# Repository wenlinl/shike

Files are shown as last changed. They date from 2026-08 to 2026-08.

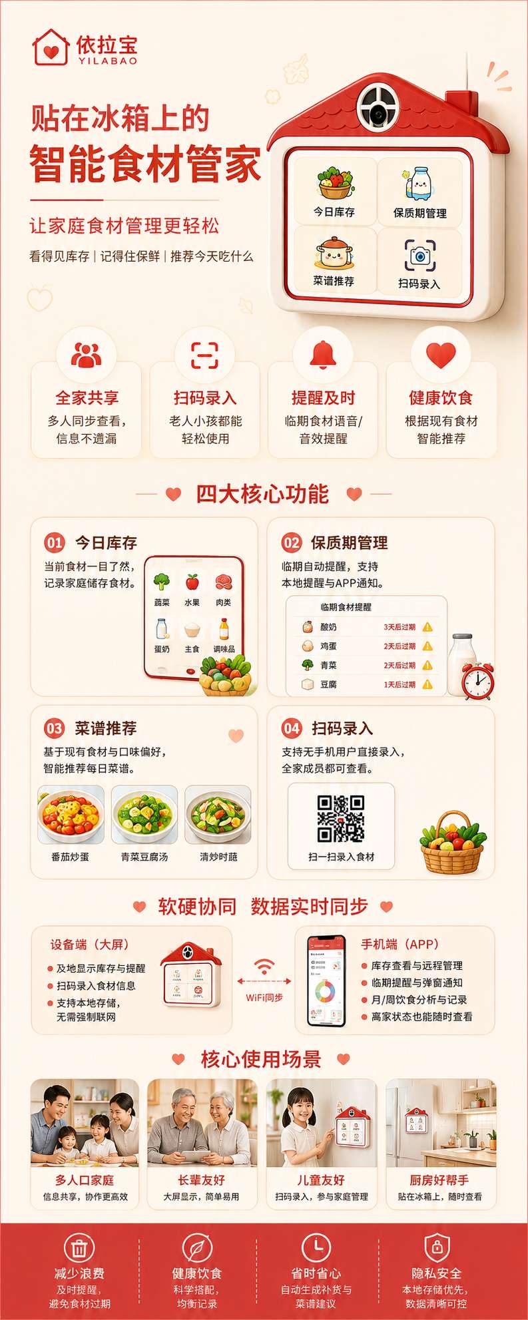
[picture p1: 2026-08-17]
media/产品宣传图/03-宣传海报-B.jpg

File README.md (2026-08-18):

# 食刻 ShiKe · 冰箱食品保质期智能管理

> Slogan：**食刻在场，不浪费每一份食材**

食刻是一台贴在冰箱上的 AI 食品扫描台：把食品拿到镜头前扫一下，云端 AI 认出它是什么、能放多久，库存自动记账；屏幕、手机端和大屏随时告诉你谁快过期、能做什么菜。

核心链路：**扫（拍照）→ 认（云端视觉 AI）→ 记（库存 ±1）→ 显（屏幕 + H5 + 大屏）**，已作为端到端可演示产品跑通——已有可演示原型机、硬件已烧录、后端已上线、H5/大屏可用、3D 打印外壳完成。

---

## 在线演示

| 入口 | 链接 | 说明 |
|---|---|---|
| H5 手机端 | https://tuvmkt.com/shike-h5.html | 首页 / 扫描 / 库存 / 菜谱 / 我的（iPhone 适配） |
| 大屏版 | https://tuvmkt.com/shike-web.html | 库存排行 / 临期提醒 / 周度菜谱 / 月度统计 |
| 硬件交互模拟 | [shike-hardware-demo.html](shike-hardware-demo.html) | 本地浏览器即可体验设备交互全流程 |
| 代码仓库 | https://github.com/wenlinl/shike | 固件 / 后端 / 前端 / 文档 |

> 演示依赖：浏览器 + 摄像头权限 + 联网（识别走云端 `https://tuvmkt.com/api/scan`）；首页 / 库存 / 菜谱 / 我的为演示数据（接口已就绪），扫描页为真实 AI 识别。

## 宣传素材

| 类型 | 位置 | 说明 |
|---|---|---|
| 宣传视频 / 产品宣传图 / 软件示意图 | [media/](media/) | 路演与对外展示素材存档（含分类索引 README） |

---

## 问题与机会

- **全球每年约 1/3 的食物被浪费**，中国年浪费超过 1 亿吨；家庭冰箱保有量超 3 亿台。
- 核心痛点：**"放进去就忘"**——临期食品被遗忘、重复购买、过期浪费。
- 现有方案：换整台智能冰箱（成本数千至上万元、渗透率低），或手动录入 App（繁琐、难以坚持）。
- 食刻的机会：**对存量电器进行智能化+AI改造 + 零学习成本**，把食材管理压缩到"一次按键 / 一次经过镜头"。

## 产品与功能

| 模块 | 已实现能力 |
|---|---|
| 硬件扫描台 | T5-E1 单板：放入 / 取出 → 倒计时拍照 → 上传识别 → 结果上屏 |
| 云端 AI 识别 | 品名 + 保质期 OCR，低置信不入库，实时识别 |
| 家庭库存 | 按容器（冰箱 / 零食柜 / 药盒 / 调料柜 / 主食柜）统计，补给 / 消耗双模式 |
| 营养分析 | 评估饮食均衡与营养摄入，给出改善建议 |
| 购物清单 | 根据库存与临期情况自动生成补货清单 |
| 家庭共享 | 多位成员实时同步、分工录入、通知提醒 |
| 浪费统计 | 月度过期/浪费数据汇总，直观展示节省与减量效果 |
| 过期处理建议 | 临期食材自动给出烹饪或处理建议，物尽其用 |
| 手机 H5 | 首页总览 / 扫描 / 库存 / 菜谱 / 我的（成员、购物清单、通知） |
| 大屏面板 | 库存排行、临期提醒、周度菜谱、月度统计 |
| 结构外观 | 3D 打印小房子造型外壳（米白机身 + 红屋顶 + 磁吸后盖） |

---

## 目标人群

- 核心人群：注重健康与性价比的中国家庭，尤其是多口之家（老人/儿童同住）、大城市的独居单身人士、厨房新手与健身人群；
- 延展人群：食堂 / 餐饮 / 药房等 B 端客户（合规盘点需求）；
- 出海方向：日本家庭（食品浪费意识强、包装日期规范，对食材管理需求明确）。

---

## 理想使用场景

### 场景一：批量采购入库（门内连续扫描，像超市扫码）

买菜回家后一次放入十几件食物，不需要逐件操作：

1. 把贴在**冰箱门外**的磁吸扫描版取下；
2. 贴到**冰箱门内侧**（此时门是开着的，理想情况冰箱门与冰箱呈垂直夹角，镜头正对过门通道）；
3. 点击按钮进入**扫描模式**；
4. 把食物放进冰箱时经过扫描镜头；
5. 镜头自动识别并发出**"滴"的一声**（像超市扫货），屏幕即时显示"已录入：牛奶 ×1"；
6. 关门后设备回到待机，弹出本次汇总"放入 12 件 / 取出 0 件"一次确认。

> 一句话：**买完菜往冰箱里放，经过镜头就自动记账，全程零手动输入。**

### 场景二：单品放入 / 取出（门外单品扫描）

日常临时拿取一件食品：

1. 设备**仍然贴在冰箱上**，无需取下；
2. 点击屏幕进入**扫描模式**；
3. 拿起食物对着镜头扫一下；
4. **立刻上传**云端识别，屏幕显示品名 / 保质期，库存 ±1。

> 一句话：**拿起扫一下，放回已记账。**

### 场景三：日常待机（展示板）

不扫描时设备常显**时钟 + 临期/过期提醒 + 今日菜谱**，按任意键唤醒，是冰箱门上的"第二块屏"。

---

## 系统架构

```text
┌─ 硬件（T5-E1 单板）──────────────────────┐
│ 摄像头 → 拍照 → HTTPS multipart 上传       │
│ 屏幕显示：识别结果 / 临期提醒 / 操作引导     │
└───────────────┬─────────────────────────┘
                ▼
        POST /api/scan（图片 + deviceId + action）
                ▼
┌─ 云端（已部署 tuvmkt.com）────────────────┐
│ 视觉 AI：品名 + 保质期 OCR                  │
│ 业务：库存 ±1 / 成员 / 菜谱 / 购物清单 / 通知 │
│ 存储：SQLite 15 张表（FoodItem / ScanLog / …）│
└───────────────┬─────────────────────────┘
                ▼
┌─ 消费端 ─────────────────────────────────┐
│ 设备屏幕 / H5 手机端 / 大屏 Web             │
└───────────────────────────────────────────┘
```

## 技术栈

| 层 | 技术 |
|---|---|
| 硬件 | T5-E1（SPARKLEIOT T5AI DEV）：ST7789 触控屏 + GC2145 摄像头 + 板载音频 |
| 固件 | TuyaOpen（C，`app_xzd.c`），WiFi 凭据已打码 |
| 视觉 AI | 火山方舟 `doubao-seed-2-1-turbo-260628`（关闭思考），低置信不入库 |
| 后端 | Next.js + Prisma + SQLite，Docker 部署，11 个 API / 15 张表 |
| 前端 | H5（5 Tab）、大屏 Web、硬件交互模拟页 |

## 云架构与 AWS 规划

**当前**：境外 VPS 部署后端（tuvmkt.com）+ 火山方舟视觉模型。

**规划（面向规模化与出海）**，整体构建于亚马逊云科技：

- **存储与数据库**：S3（扫描图片）+ DynamoDB / RDS（库存、家庭、设备数据）；
- **AI 能力**：Amazon Bedrock / Amazon Rekognition 提供食品识别与保质期日期 OCR；
- **接入层**：API Gateway + Lambda 支撑扫描请求，Cognito 负责家庭与设备鉴权，CloudFront 加速 H5 与大屏；
- **区域**：首发部署 `ap-northeast-1`（东京），满足日本个人信息保护法（APPI）数据合规，并为欧美扩展预留架构。

---

## 仓库结构

```text
.
├── README.md                     # 本文档
├── shike-h5.html                 # 移动端 H5（iPhone 16 适配，底部 5 Tab）
├── shike-web.html                # 大屏版 Web Demo
├── shike-hardware-demo.html      # 硬件交互模拟 Demo（本地可开）
├── Demo操作说明.md                # 3 分钟演示步骤与依赖说明
├── docs/                         # 产品 / 后端 / 固件 / 结构文档
├── hardware/case-3d/             # 3D 打印外壳（STL + 预览图 + 建模脚本）
├── firmware/                     # 硬件烧录源码（T5-E1 TuyaOpen，WiFi 凭据已打码）
└── backend/                      # 后端接口参考代码（Prisma + Next.js，已部署）
```

## 文档索引

| 文档 | 内容 |
|---|---|
| [docs/产品文档.md](docs/产品文档.md) | 产品逻辑、已实现能力、未实现项（v3） |
| [docs/后端对接说明.md](docs/后端对接说明.md) | 11 个 API 契约、数据库 15 张表、部署方式 |
| [docs/固件烧录需求.md](docs/固件烧录需求.md) | 硬件 / 开发环境 / 烧录 SOP |
| [docs/硬件描述.md](docs/硬件描述.md) | 硬件原型描述与 BOM |
| [docs/磁吸门版硬件设计方案.md](docs/磁吸门版硬件设计方案.md) | 门内连续扫描形态、低延时管线、BOM 成本 |

---

## 未来迭代方向

1. **磁吸门版 v2 硬件**：ESP32-S3 单板（BOM ¥70–90），磁吸 + 锂电 + 干簧管，可贴门内/门外两用，比现开发板更小更便宜更贴场景；
2. **门内连续扫描**：开门自动进入扫描模式、自动取景抓帧、批量入队、关门汇总一次确认（对应场景一）；
3. **板端边缘识别 + 本地目录缓存**：已知食品 <0.6 秒免云端，越用越快（家庭重复购买多）；
4. **离线兜底**：关门断网时本地记录，开门窗口自动补传；
5. **商业化基础设施**：设备 Token 鉴权、OTA 升级、多家庭共享、远程查看；
6. **B 端扩展**：食堂 / 餐饮 / 药房合规盘点 SaaS；
7. **出海日本首发**：食品浪费社会共识最强、包装日期体系规范、无外挂扫描台竞品；AWS 东京部署，合规先行；
8. **数据增值**：门内温度修正保质期（DS18B20）、菜谱推荐、购物清单自动生成。
9. **一键补货**：联动生鲜电商 / 商超，库存告急时一键下单补货。

## 演示准备

- 手机 / 电脑浏览器（Chrome / Safari 均可）；
- 扫描功能需要**摄像头权限 + 联网**；
- 首页 / 库存 / 菜谱 / 我的目前为演示数据（后端接口已就绪），扫描页为真实识别；
- 可选硬件演示：T5-E1 扫描台（放入 / 取出 → 3 秒倒计时 → 拍照 → 屏幕显示结果），数据与 H5 同一后端；
- 断网 / 摄像头不可用时页面自动回退演示数据，不影响讲解。

## 说明

- 视觉识别：火山方舟视觉模型，低置信不入库；
- 数据库：SQLite 15 张表，含种子数据与真实扫描数据；
- 后端完整可部署工程保留在本机与服务器，仓库内为参考代码；部署细节见 `backend/README.md` 与 [docs/后端对接说明.md](docs/后端对接说明.md)。

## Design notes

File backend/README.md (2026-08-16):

# 食刻 后端（参考代码）

已部署：https://tuvmkt.com（Next.js + Prisma + SQLite，Docker）

- API：/api/scan（硬件上传识别+库存）、/api/items、/api/reminders、/api/members、/api/shopping-list、/api/notifications、/api/recipes、/api/consume、/api/catalog、/api/device/heartbeat、/api/device/state
- 数据库：SQLite 15 张表（schema 见 prisma/schema.prisma）
- 本目录为后端参考代码（schema / 种子 / API 路由）；完整可部署工程保留在本机与服务器，线上地址 https://tuvmkt.com

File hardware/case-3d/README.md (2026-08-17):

# 食刻 · 冰箱贴智能屏 3D 打印外壳

按产品示意图做的**扁平小房子造型**：米白机身 + 红色山墙屋顶（在机身顶部、
左坡带烟囱）、机身正面上部正中间 **17×17mm 方形摄像头口**、正面下方大屏幕窗口、
底部正中间充电口（12mm 宽、距底 17mm 高）、右侧按键与喇叭孔、背面磁吸后盖。

主板竖装：**高 87mm × 宽 50mm × 厚 20mm**，屏幕窗口 **48mm 宽 × 67mm 高**。

## 文件清单

| 文件 | 颜色 | 说明 |
|---|---|---|
| `食刻-前壳.stl` | 米白 | 机身：屏幕窗口、摄像头通道、USB/按键/喇叭口、螺丝柱 |
| `食刻-屋顶-红色.stl` | 红 | 山墙屋顶（含烟囱），胶水贴到机身顶部 |
| `食刻-后盖.stl` | 米白 | 平板后盖：4×Ø10×1.6mm 磁铁沉孔 + M2 螺丝孔 + 主板支撑柱 |
| `食刻-主板参考.stl` | — | 主板占位模型（只做装配检查，**不要打印**） |
| `build_case.py` | — | 参数化建模脚本，改 `CFG` 后重新生成 |
| `render_ray.py` | — | SDF 光线追踪渲染预览图 |
| `预览-正面.png / 预览-背面.png / 预览-装配图.png` | — | 预览图 |

## 主板信息（已确认）

- 型号：**T5-E1（SPARKLEIOT T5AI DEV）**，TuyaOpen 平台 `t5ai`
- 实测：**87 × 50 × 20 mm**（长×宽×厚，竖装），屏幕 **67 × 48 mm**
- 板载：ST7789 240×320 触控彩屏、CST816X 触控、GC2145 摄像头、
  内置音频、microSD、按键 GPIO8、USB 供电

## 尺寸（当前模型）

- 机身：66 × 107 × 26.8 mm（主板 50×87×20 + 壁厚 + 后盖）；
  红色屋顶在机身顶部之上（屋脊高出 8.5mm），整机总高约 115.5mm
- 屏幕窗口：48 × 67 mm（居中，比屏大 1.5mm 间隙）
- 摄像头口：17×17mm 方形，正中间（x=0，y=44），背后有竖直通道连通板载镜头
- 充电口：底部正中间，12mm 宽、从底部往上 17mm 高的开口（USB-C 插头从下方插入）
- 螺丝：M2×6 自攻 ×4；磁铁：Ø10×1.6mm N52 ×4；主板与后盖间建议垫 1~2mm 泡棉

## 装配

1. 前壳正面朝下打印（米白），屋顶件平放打印（红色）；后盖平放打印（米白）
2. 屋顶件放到机身顶部贴 3M 双面胶或热熔胶（屋顶底边正好落在机身上缘）
3. 后盖沉孔放入 4 颗磁铁（注意 4 颗极性一致）
4. 主板放进机身内腔：屏幕对准窗口，摄像头镜头朝上/朝前对准通道
5. 盖上后盖，M2×6 自攻螺丝 ×4 锁紧；USB 线从底部开口穿出

> 板载摄像头镜头请对着 17×17 方孔确认，如位置有偏差，改 `CFG` 里的
> `cam_y` / `cam_win_y` 重新生成即可。

## 重新生成

```bash
python3 build_case.py --part all --res 0.45   # 重新生成全部 STL
python3 render_ray.py                         # 重新渲染预览图
```

尺寸全部集中在 `build_case.py` 顶部 `CFG`（主板、屏幕、摄像头、USB、按键、
屋顶三角形顶点、烟囱位置等均为参数）。

## Bambu Studio 使用步骤

1. 在 Windows 电脑从 [Bambu Lab 官网](https://bambulab.com/zh-cn/bambu-studio)
   下载安装 Bambu Studio；
2. 新建工程 → 导入 `食刻-前壳.stl`、`食刻-屋顶-红色.stl`、`食刻-后盖.stl`；
3. 摆放：前壳**正面朝下**（屏幕窗口贴热床），后盖平放，屋顶件倒扣/平放均可；
4. 材料建议：PLA / PETG，层高 0.2mm；
5. 分色：屋顶件直接用红色耗材打印，机身/后盖用米白耗材——天然两色，
   无需 AMS 上色；屏幕边框如需红色，可用油漆笔手涂；
6. 切片后检查：无悬垂大角度，一般不需要支撑；屋顶件较薄（2.2mm），
   打印后注意别掰断；
7. 打印完成后按上面“装配”步骤组装。

## 待确认

- 摄像头在主板上的实际位置与镜头朝向（当前按正中间上部假设）
- 屏幕边框是否需要红色装饰环（当前窗口边缘即机身色，可手涂）
- 如需挂耳/挂钩可再加参数

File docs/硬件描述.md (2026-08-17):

# 食刻 · 硬件原型描述（供 STACK ANYWAY 生成原型与烧录代码）

> 用途：交给 STACK ANYWAY 构建硬件原型并生成烧录代码。目标板为 **T5-E1（SPARKLEIOT T5AI DEV）**；若平台组件库中没有该型号，可用「T5AI / BK7258 开发板 + ST7789 触控屏 + GC2145 摄像头」替代模型，生成的代码只需替换板级驱动。

## 1. 产品一句话

「食刻」是一台贴在冰箱上的食品保质期管理扫描台：用户把食品拿到镜头前按一下按钮，设备拍照上传云端 AI 识别，屏幕显示品名、当天日期时间与保质期；待机时屏幕常显临期 / 过期提醒；库存按容器（冰箱 / 零食柜 / 药盒 / 调料柜 / 主食柜）统计，支持补给 / 消耗双模式。

## 2. 硬件组成（BOM）

| 部件 | 型号 / 规格 | 数量 | 用途 |
|---|---|---|---|
| 主控 + 屏 + 摄像头（单板） | **T5-E1（SPARKLEIOT T5AI DEV）**：ST7789 240×320 触控彩屏 + CST816X 触控 + GC2145 DVP 摄像头 + 内置音频 codec/功放 + microSD | 1 | 主控 + 交互 + 拍照上传云端 |
| 蜂鸣器（可选） | 有源蜂鸣器 3.3V | 1 | 备选提示音（板载音频可替代） |
| 温度传感器（可选） | DS18B20 | 1 | 冰箱温度异常提醒 |
| 门磁（可选） | 干簧管 + 小磁铁 | 1 | 开门亮屏提示（辅助，非主链路） |
| 供电 | USB-C 线 + 5V 充电头 / 充电宝 | 1 | 固定供电，无需电池 |
| 外壳 | 3D 打印（底座 + T5 立架） | 1 | 结构件 |

## 3. 电路连接

### 3.1 T5-E1（SPARKLEIOT T5AI DEV）板载外设引脚

| 外设 | 引脚 |
|---|---|
| 显示 ST7789 240×320（SPI0） | SCK=44、MOSI=46、CS=45、DC=47、RST=6、BL=9（背光高有效） |
| 触控 CST816X（I2C1） | SCL=20、SDA=21、RST=23 |
| 摄像头 GC2145（DVP） | 控制 I2C0：SCL=0、SDA=1；24MHz MCLK；DVP 数据总线平台固定引脚 |
| 音频 | 内置 codec + 功放，spk_en=GPIO7（高有效），16kHz 单声道 + AEC |
| 按键 | GPIO8（低有效，下降沿中断） |
| microSD（SDIO MODE1） | CLK=14、CMD=15、D0–D3=16~19 |
| UART0（调试 / 扩展） | TX=11、RX=10（115200，即板载 USB 串口） |
| DS18B20（可选） | 空闲 GPIO + 4.7kΩ 上拉 |
| 干簧管（可选） | 空闲 GPIO，INPUT_PULLUP + 中断 |

> 相机、屏幕、触控、音频全部板载，**无需外挂 XIAO Sense / 摄像头 / 蜂鸣器**（蜂鸣器仅作备选）。

## 4. 通信协议

### 4.1 板载拍照（T5-E1 单板）

点【扫描】→ 板载 GC2145 抓一帧（640×480，参考 copy 工程：实时预览 + 触控定格）→ 直接上传云端；不再经过外挂相机。

### 4.2 T5-E1 → 云端中继（HTTP）

- `POST /capture`：multipart 上传 image（JPEG VGA）+ deviceId + timestamp + action + container → 返回 items JSON（同 4.1 result 结构）；
- `GET /items`：库存清单（按容器分组，组内按剩余天数升序）；
- `GET /reminders`：提醒列表（临期 / 过期置顶）；
- `POST /items`：确认入库 / 出库。

## 5. 设备状态机（固件逻辑）

```text
IDLE（T5 显示临期/过期提醒，等待触摸）
 → 触摸 → CHOOSE（弹出「补给 / 消耗」两个按钮）
 → 选择 → READY（提示“请把食品放到镜头前”）
 → 按【扫描】 → SCAN（“咔嚓”声 → 板载 GC2145 抓帧 → 组装 JSON → POST /capture → 等待结果，超时 8s）
 → RESULT（T5 显示：品名、当天日期时间、保质期/到期日、建议容器；用户确认 → 库存 +1/-1 → 回 IDLE）
失败 / 超时 → 显示“没看清，再扫一次”，回 READY
断网 → OFFLINE（显示最近库存与提醒 + “网络不好，先不扫描”）
```

## 6. 供电

- T5-E1 单板 USB 5V 供电（推荐 5V / 2A 充电头或充电宝）；
- 不用锂电池（低温冰箱场景不适合）。

## 7. 外壳与装配（原型）

- 底座：T5-E1 摄像头开孔朝前（镜头在板载位置）+ USB 走线孔；
- 立架：屏幕斜 30° 朝用户（T5-E1 屏与摄像头同面，支架把镜头对准物品）；
- 装配：单板 + USB 电源线，无需杜邦线；
- 演示道具：日期贴纸（打印「2026-08-17 到期」标签贴在牛奶盒上）。

## 8. 避坑

- 蜂鸣器不能直接接 GPIO，需三极管驱动；
- 大块内存用 `ps_malloc()`，`loop()` 里不用 `delay()`；
- Strapping 引脚 GPIO 0 / 3 / 45 / 46 不要接外围电路；GPIO 26~37 为内部 Flash/PSRAM 专用，不外接；
- 摄像头 DVP 数据总线为 T5AI 平台固定引脚，不要改线；
- 识别失败不猜日期，提示重扫。

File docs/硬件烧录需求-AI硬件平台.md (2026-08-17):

# 硬件烧录需求文档（给 AI 硬件平台）

> 项目：食刻（Shike）· 冰箱食品保质期 + 零食存储柜
> 产品名：食刻 ｜ Slogan：食刻在场，不浪费每一份食材
> 日期：2026-08-15

## 0. 一句话需求

把「食刻」固件烧录到 **T5-E1（SPARKLEIOT T5AI DEV）单板**，烧录后设备作为交互主界面：**待机显示临期 / 过期提醒 → 触摸选择「补给 / 消耗」→ 板载 GC2145 摄像头完成“扫一下”识别闭环**。

## 1. 目标硬件

| 部件 | 型号 / 规格 | 角色 |
|---|---|---|
| 主控 + 屏 + 摄像头（单板） | **T5-E1（SPARKLEIOT T5AI DEV）**：ST7789 240×320 触控彩屏 + CST816X 触控 + GC2145 DVP 摄像头 + 内置音频 codec/功放 + microSD | 主控 + 交互 + 拍照：待机提醒、补给 / 消耗选择、结果显示、板载拍照 |
| 相机 | 板载 **GC2145 DVP**（640×480 @ 15fps 预览，可拍照） | 拍照上传（**替代外挂 XIAO Sense**） |
| 声音 | 内置音频 codec + 功放（spk_en GPIO7） | “咔嚓”快门声 + 提醒音（蜂鸣器可省） |
| 蜂鸣器（可选） | 有源蜂鸣器 3.3V（三极管驱动） | 备选提示音 |
| 温度（可选） | DS18B20 | 冰箱温度异常提醒 |
| 门磁（可选） | 干簧管 + 磁铁 | 开门亮屏提示（辅助） |

> 注：T5-E1 板载摄像头已确认可用（GC2145 DVP），**外挂 XIAO Sense 不再需要**。

## 2. 平台与工程环境

| 项 | 值 |
|---|---|
| IDE | TuyaOpen IDE（VSCode / Cursor 扩展） |
| SDK | TuyaOpenSDK（`/Users/lwl/TuyaOpenIDE/TuyaOpenSDK`） |
| 目标平台 | `t5ai` |
| 板卡 | **T5-E1 / SPARKLEIOT T5AI DEV**（id：`sparkleiot-t5ai-dev`，kconfig：`SPARKLEIOT_T5AI_DEV`） |
| 板卡配置 | `SPARKLEIOT_T5AI_DEV.config` |
| 产品 PID | `pf1xhzdr2zbc2nhw` |
| 当前工程 | `copy`（Tap-to-take-photo 样板：板载摄像头实时预览 + 触控定格 + UART0 上报，改造为「食刻」） |

## 3. 固件烧录需求

### 3.1 构建产物（`source/embedded/dist/`）

| 镜像 | 用途 |
|---|---|
| `copy_QIO_1.0.0.bin` | **全量镜像，烧录主用**（当前产物：`source/embedded/dist/copy_1.0.0/`） |
| `copy_UA_1.0.0.bin` | 应用升级包（后续 OTA / 差分升级用） |
| `copy_UG_1.0.0.bin` | 通用升级包（备用，不与 QIO 混用） |

构建命令：`cd source/embedded && tos.py build`

### 3.2 烧录工具与参数

- 工具：`tyutool_cli` v3.2.8（`$OPEN_SDK_ROOT/tools/tyutool/tyutool_cli`，先 `. ./export.sh` 加载环境）
- 芯片：`-d t5`
- 镜像：QIO 全量 `embedded_QIO_1.0.1.bin`
- 端口：**以 `tyutool_cli list-ports` 实际输出为准**（T5 枚举为双串口；当前示例：`/dev/cu.usbmodem5AAE1670681` / `...683`；历史端口曾为 `/dev/cu.usbserial-110`）
- 波特率：`-b 460800`

### 3.3 烧录步骤

```bash
# 1) 加载 TuyaOpen 环境
cd /Users/lwl/TuyaOpenIDE/TuyaOpenSDK && . ./export.sh

# 2) 识别 T5 端口（插上开发板后执行，输出 JSON 列表）
"$OPEN_SDK_ROOT/tools/tyutool/tyutool_cli" --plain list-ports --json

# 3) 烧录全量镜像（端口替换为 list-ports 输出的主口）
"$OPEN_SDK_ROOT/tools/tyutool/tyutool_cli" --plain write -d t5 \
  -f /Users/lwl/TuyaOpenIDE/projects/copy/source/embedded/dist/copy_1.0.0/copy_QIO_1.0.0.bin \
  -p /dev/cu.usbmodem5AAE1670681 -b 460800

# 4) 烧录完成后重新上电 / 复位，观察屏幕
```

### 3.4 烧录验收（必须全过）

- [ ] 屏幕点亮，显示「食刻」待机页（临期 / 过期提醒置顶）
- [ ] 触摸屏幕可弹出「补给 / 消耗」两个按钮
- [ ] 板载 GC2145 摄像头取景 / 拍照正常（640×480 @ 15fps）
- [ ] 拍照上传云端并回显结果（品名 + 日期 + 保质期）
- [ ] Wi-Fi 连接涂鸦云成功（PID 有效、授权码正常）

### 3.5 字体与字符集（屏显约束）

- 屏显中文**必须使用 16×16 GB2312 点阵字库（HZK16）**，数字 / 字母用 8×16 或 16×16 ASCII 点阵；
- **禁止矢量 TTF、抗锯齿、灰度、亚像素渲染**：输出纯 1-bit 二值点阵，字符像素严格对齐网格，防止缺笔画、碎像素；
- 字符集限定 GB2312 简体中文 + 数字字母 + 常用符号，界面文案须全部在字库字符集内（不要生僻字、全量 Unicode，避免缺字乱码）；
- 大字（倒计时 3→2→1）用点阵按**整数倍最近邻放大**，禁止非整数缩放。

## 4. 固件功能需求（烧录后运行什么）

1. **待机态**：从云端 / 本地拉取库存，屏幕常显临期 / 过期置顶列表；
2. **触摸选择**：点击屏幕 → 弹出「补给 / 消耗」按钮；
3. **扫描引导**：选择后提示“请把食品放到镜头前”，等待按【扫描】（板载按键 GPIO8 或屏幕按钮）；
4. **板载拍照**：GC2145 抓一帧（640×480 JPEG/YUV）→ 组装 JSON 直接上传云端（**不再依赖外挂 XIAO Sense**）；
5. **结果展示**：收到识别 JSON 后，屏幕显示**品名、当天日期时间、保质期 / 到期日、建议容器**；
6. **库存变更**：用户确认 → 上报涂鸦云 / 中继，库存 +1（补给）/ -1（消耗）；
7. **声音反馈**：扫描时“咔嚓”（板载音频或蜂鸣器），过期时警示音；
8. **断网降级**：显示本地最近库存 + “网络不好，先不扫描”。

## 5. 外设 / 引脚需求

| 外设 | 连接 |
|---|---|
| 显示 ST7789 240×320（SPI0） | SCK=44、MOSI=46、CS=45、DC=47、RST=6、BL=9（板载） |
| 触控 CST816X（I2C1） | SCL=20、SDA=21、RST=23（板载） |
| 摄像头 GC2145（DVP） | 控制 I2C0：SCL=0、SDA=1；24MHz MCLK；DVP 数据总线平台固定引脚（板载） |
| 音频 | 内置 codec + 功放，spk_en=GPIO7（高有效）（板载） |
| 按键 | GPIO8（低有效，下降沿中断）（板载） |
| microSD（SDIO MODE1） | CLK=14、CMD=15、D0–D3=16~19（板载） |
| UART0（调试 / 扩展） | TX=11、RX=10（115200） |
| DS18B20（可选） | 空闲 GPIO + 4.7kΩ 上拉 |
| 干簧管（可选） | 空闲 GPIO，INPUT_PULLUP + 中断 |
| 供电 | USB 5V（板载稳压；无需外接相机 / 蜂鸣器电源） |

## 6. 交付物与验收

- 可烧录 QIO 镜像 + 源码（烧录 SOP 附命令与端口确认步骤）；
- 烧录后三项必验：**待机提醒屏显、补给 / 消耗触控、UART 指令闭环**；
- 设备可上涂鸦云（PID `pf1xhzdr2zbc2nhw`、授权码有效）。

## 7. 注意事项

- **端口每次插拔会变**：先 `list-ports` 再烧，不要写死端口；
- T5 是双串口设备：烧录用主口，失败换另一个口重试；
- QIO 为全量镜像，UG / UA 不混用；后续升级用 UA；
- **T5-E1 为单板方案**：屏 / 触控 / 摄像头 / 音频全部板载（见 §5 引脚表），外挂 XIAO Sense 已不需要；
- `copy` 工程即「点按拍照」样板（板载 GC2145 预览 + 触控定格 + UART0 上报），是食刻固件的改造起点；
- 产品名已定：**食刻**（食刻在场，不浪费每一份食材）；固件屏显文字同步改为「食刻」。

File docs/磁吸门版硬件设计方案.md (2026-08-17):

# 食刻 · 磁吸门版硬件设计方案（成本最低版）

> 日期：2026-08-17
> 目标产品形态：一块磁吸屏版，贴在**冰箱门内侧**时开门自动进入连续扫描模式，实时录入放进/取出的食物；需要单品扫描时**取下在门外扫**；平时**贴门外做展示板**。硬件全部重新设计，目标：BOM 成本最低 + 门内扫描时延最低。

---

## 1. 产品形态

单块"磁吸屏版"（约 10×7×2cm，300g 内）：

- **背面**：4 颗 N52 磁铁 + 硅胶垫，内门/外门铁板均可直接吸；
- **正面**：广角摄像头 + 补光灯 + 2.4" 彩屏 + 2 个大物理按键；
- **供电**：内置 1200mAh 锂电 + USB-C 充电（摘下充电，像手机一样 1–2 周充一次）；
- **切换位置**：单手取下换面贴，约 10 秒，无需拆线、无需支架。

## 2. 三个使用场景

| 场景 | 触发 | 交互 | 时延目标 |
|---|---|---|---|
| 门内连续扫描 | 干簧管检测到开门 | 自动连续取景，每件食物经过即抓帧识别，屏幕即时显示"已录入：牛奶×1"；关门后弹出本次汇总一次确认 | 已知品 <0.6s；新品 1.5–2.5s |
| 门外单品扫描 | 按键 / 触摸屏 | 取下对准单品，按一下自动拍照识别，显示品名/日期/保质期 | <1s（已知品） |
| 门外展示板 | 静止待机 | 常显时钟 + 临期提醒 + 今日菜谱，按任意键唤醒 | 唤醒 <0.3s |

## 3. 设计约束与关键决策

### 3.1 冰箱门是法拉第笼（最重要的时序约束）

金属冰箱门关门后对 2.4GHz Wi-Fi 衰减极大。因此**不要设计成"关门也连着云"**：

- **通信窗口 = 开门扫描的时段**：扫描时恰好门开着，此时连 Wi-Fi 上传识别；
- 关门后设备进入低功耗待机，结果先落本地（NVS/flash），下次开门补传；
- 这同时解决电池续航——不需要常连接保活。

### 3.2 低温与凝露

- 主舱位温度 2–8°C，锂电可用（容量略降），**不要放进冷冻室**；
- 镜头用防雾镀膜 + 壳体密封，开机短暂预热（CPU/背光发热）可加速除雾；
- 板件做三防漆，防凝露短路。

### 3.3 湿手场景：不用触屏

冰箱前手指可能湿/冷/有油，触屏体验差且贵。用 **2 个超大物理按键**（扫描 / 确认切换），成本低 ¥8–10，可靠性更高。

### 3.4 低延时 = 双级识别 + 目录缓存

"实时扫描"的关键是别让每件食物都走完整云端链路：

- **第一级（板端，每帧）**：运动检测 + 轻量食品分类（ESP-DL / TFLite Micro），判断"有没有食物、是什么品类（奶/蛋/菜/肉/饮料）"，100–300ms 出结果；
- **第二级（云端，仅最佳帧）**：精确品名 + 保质期 OCR（复用现有 tuvmkt.com /api/scan），异步补全；
- **目录缓存**：首次识别结果（品名 + 保质期天数）写回板端本地目录，同物第二次扫描直接本地命中，<0.6s 免云端——家庭场景绝大多数是重复购买（牛奶、鸡蛋、蔬菜），越用越快；
- **批量队列**：门内连续扫不逐件等确认，先连续抓帧入队，关门后汇总"本次 5 件：放入 4 / 取出 1"一次确认。

### 3.5 成本最低 = 砍外设

单板、单屏、单镜头、单电池；砍掉触屏、SD 卡、音频 codec、双摄像头、e-ink、Linux 板。

## 4. 推荐架构

```mermaid
flowchart LR
    subgraph DEV["磁吸屏版（ESP32-S3 单板）"]
        CAM["广角摄像头 + 补光"]
        LCD["2.4\" ST7789 彩屏"]
        BTN["物理按键×2 + 干簧管"]
        EDGE["板端轻量分类<br/>（运动检测→抓最佳帧→品类判断）"]
        CACHE["本地目录缓存<br/>（品名/保质期天数）"]
        CAM --> EDGE
        EDGE --> CACHE
        EDGE --> LCD
        BTN --> EDGE
    end
    subgraph CLOUD["云端（复用 tuvmkt.com）"]
        API["/api/scan + 批量队列接口"]
        AI["视觉识别 + 保质期 OCR"]
        DB[("FoodCatalog 目录")]
    end
    DEV <-- "开门窗口内上传最佳帧" --> API
    API --> AI
    API --> DB
```

## 5. 硬件组成与 BOM（单位成本估算，2026-08）

| 部件 | 选型 | 单价（元） | 说明 |
|---|---|---:|---|
| 主控 | ESP32-S3-WROOM-1 N16R8 | 18 | 240MHz + 8MB PSRAM，板端跑轻量模型；Wi-Fi 2.4G |
| 摄像头 | OV5640 模块（5MP，广角镜头可选） | 15 | 门内距离 30–60cm，分辨率够 OCR；预算紧可换 OV2640（¥8） |
| 屏幕 | 2.4" ST7789 320×240 SPI | 13 | 不做触屏，湿手友好 |
| 按键/传感 | 大按键×2 + 干簧管×1 | 2 | 干簧管 + 门框小磁铁（¥1）检测开门 |
| 供电 | 1200mAh 锂电 + TP4056 充电 | 10 | 开门扫描 ~400mA 突发，待机 µA 级，1–2 周充一次 |
| 板基 | LDO + 阻容 + 4 层 PCB | 12 | 小批量 |
| 灯光/声音 | 白光 LED×2 + 有源蜂鸣器 + 三极管 | 3 | 低光补光 + 识别成功提示音 |
| 磁吸 | N52 磁铁×4 + 硅胶垫 | 4 | 开门/关门振动不脱落 |
| 温度（推荐） | DS18B20 | 3 | 设备就在冰箱里，实际温度修正保质期估算 |
| 结构 | 注塑 ABS 外壳（前后壳） | 10 | 含镜头防雾窗 |
| **合计** | | **约 90** | 低配可压到 ¥70（OV2640 + 2.0"屏 + 500mAh）；高配 <¥110 |

对比：现用 T5-E1 开发板零售约 ¥120–150，且体积、功耗、镜头自由度都不满足门内形态；重新设计后更小、更便宜、更贴场景。

## 6. 低延时管线（时延预算）

| 环节 | 耗时 | 说明 |
|---|---:|---|
| 开门唤醒（干簧管中断） | <50ms | 深度睡眠 GPIO 唤醒 |
| 取景 10fps + 运动检测 | 100–200ms | 检测到运动即开始连续抓帧 |
| 最佳帧筛选（清晰度/倾斜/距离） | <100ms | 板端质量门，跳过糊帧 |
| 板端品类分类 | 100–300ms | 已知品类先上屏 |
| 本地目录命中 | <50ms | 同物再扫免云端 |
| 云端识别 + 日期 OCR（仅新品） | 1.5–2.5s | 开门窗口内并行上传，结果异步补到卡片 |
| 关门汇总 | 即时 | 队列一次提交 |

**用户体验**：放进冰箱这个动作本身就要 1–2 秒，识别在放的过程中完成，感知上是"实时"的；已知品基本无感。

## 7. 固件状态机

```text
DISPLAY（门外展示板，低功耗：时钟/临期/菜谱，干簧管或按键唤醒）
 ├─ 检测到贴到内门 + 开门 → SCAN_DOOR
 └─ 按键 → SCAN_SINGLE

SCAN_DOOR（门内连续扫描）
 → 连续取景 10fps → 检出食物 → 抓最佳帧 → 板端分类 → 卡片入队（品类即时显示）
 → 云端异步补全品名/保质期 → 关门 → 汇总页「本次 N 件：放入/取出/跳过」→ 确认提交
 失败帧 → 忽略继续（不打断节奏）

SCAN_SINGLE（门外单品扫描）
 → 按键 → 0.5s 取景 → 自动抓帧 → 板端分类（<0.3s 先显示）→ 云端补全 → 结果页 → 确认

OFFLINE（断网兜底）
 → 板端分类 + 本地目录默认保质期 → 结果标记"待联网确认日期" → 队列本地缓存 → 开门窗口补传
```

## 8. 与现有 T5-E1 的关系：先验证、后改板

**第一步（不花一分钱，用现板验证产品逻辑）**：

1. 把现有 T5-E1 临时固定在冰箱内门（胶带/双面胶），确认最佳安装位：门上部向下 30° 俯视过门通道，镜头到手的距离 30–60cm；
2. 固件把"3 秒倒计时拍照"改成"运动检测自动抓帧"（复用现有板载 GC2145）；
3. 后端加批量队列接口（`POST /api/scan-batch`：一次上传 N 帧，返回 N 条结果）；
4. 实测：广角够不够、补光够不够、凝露情况、关门断网时本地缓存是否正常。

**第二步（验证通过后打样新板）**：

1. ESP32-S3 新板（BOM ¥70–90，可找嘉立创 5 片打样，约 ¥300–500）；
2. 板端轻量分类模型：先可用现成 MobileNet 量化版 + 30 类食品微调；
3. 目录缓存、批量队列、开门检测逻辑移植；
4. 3D 打印试装磁吸外壳 → 验证后开模。

## 9. 验收清单（新板）

- [ ] 内门吸稳，开关门不脱落；取下换外门 ≤10 秒
- [ ] 开门自动进入扫描模式，关门自动汇总
- [ ] 连续放入 3 件不同食品：已知品每件 <0.6s 上屏，无漏检
- [ ] 新品首扫 1.5–2.5s 出结果，日期 OCR 可读
- [ ] 关门断网期间扫描可离线记录，开门后自动补传
- [ ] 待机展示板模式 1–2 周不充电
- [ ] 2–8°C 连续工作 24h 无凝露、无误触发

## 10. 明确不做（本期）

- 不做触屏（湿手场景 + 成本）；
- 不做 SD 卡（flash 缓存够用）；
- 不做 e-ink 双屏（一块 LCD 两用）；
- 不做双摄像头、Linux/NPU 板、本地全量 OCR（成本与功耗不划算）；
- 不做语音播报（蜂鸣器提示音即可）。

## 预留（后续低成本加）

- OTA 升级 + 设备 Token 鉴权（商业化必需）；
- 家人远程查看（复用现有 H5）；
- 门内温湿度长期日志（DS18B20 已含，DHT11 可加 ¥2）。

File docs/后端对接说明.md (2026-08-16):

# 食刻 · 后端对接说明

> 日期：2026-08-16 ｜ 状态：✅ 已上线 tuvmkt.com（替换 workshop 应用），接口与数据库 v3 均已线上验证
> 线上地址：https://tuvmkt.com/api/*（health / scan / items / reminders / members / recipes / shopping-list / notifications / catalog / consume / device/heartbeat / device/state）
> 数据库：SQLite（服务器容器 /app/data/app.db，Docker 卷持久化），v3 共 15 张表，已含种子数据与真实扫描数据

## 1. 架构

```text
T5-E1 固件（copy 工程 app_xzd）
  │  HTTPS multipart POST /api/scan（图片 + deviceId/action/container/timestamp）
  ▼
后端（midyear-workshop 工程 · 复用其服务器/域名/火山方舟 Key）
  │  保存图片 → 火山方舟视觉模型 doubao-seed-2-1-turbo-260628 识别
  ▼
SQLite（FoodItem 当前库存 + ScanLog 流水）→ 扁平 JSON 返回固件
  │
  ▼
软件端：网页大屏 / H5 / App
  GET /api/items（库存按容器） · GET /api/reminders（临期/过期） · PATCH /api/items/[id]（改容器）
```

## 2. 接口契约

### POST /api/scan（固件上传，公开）

multipart/form-data：

| 字段 | 说明 |
|---|---|
| `image` | JPEG（640×480，30–60KB），filename=scan.jpg |
| `deviceId` | 如 `xzd-t5e1-001` |
| `action` | `in`（放入）\| `out`（取出） |
| `container` | 冰箱 \| 零食柜 \| 药盒 \| 调料柜 \| 主食柜 |
| `timestamp` | `YYYY-MM-DD HH:mm:ss`（UTC，可为空） |

响应（扁平 JSON，固件解析这些键）：

```json
{"code":0,"name":"光明鲜牛奶","scannedAt":"2026-08-15 23:22:00","expiryDate":"2026-08-17","daysLeft":2,"suggestedContainer":"冰箱","confidence":0.92,"note":""}
```

- `code!=0` 或 HTTP 非 200 → 固件显示“网络不好请重试”；
- `name` 为空 / `confidence<0.50` → 固件走 LOW_CONF，提示“没看清，重新对准再拍”；
- 后端自动：保存图片 → ARK 视觉识别 → 更新 FoodItem（in 加数量 / out 减数量，减到 0 删除）→ 写 ScanLog。

### GET /api/items?container=冰箱

```json
{"code":0,"items":[{"id":"...","name":"光明鲜牛奶","category":"乳制品","container":"冰箱","quantity":1,"expiryDate":"2026-08-17","scannedAt":"...","daysLeft":2,"confidence":0.92,"note":"","status":"soon"}]}
```

按容器筛选、剩余天数升序；`status` = normal / soon（≤3 天）/ expired。

### PATCH /api/items/[id]

```json
{"container":"零食柜"}
```

手动修改容器分类。

### GET /api/reminders

```json
{"code":0,"soon":[{"id":"...","name":"...","container":"冰箱","quantity":1,"expiryDate":"2026-08-17","daysLeft":2}],"expired":[]}
```

## 3. 数据库模型（Prisma / SQLite）

- `FoodItem`：当前库存（`@@unique([name, container, deviceId])`，in 加数量 / out 减数量）；
- `ScanLog`：每次扫描流水（最近记录 / 统计）。

### 3.1 数据库需求（v3 · 按最新软件端 食刻-H5手机端.html 对齐）

最新软件端的页面与数据面：

| 页面 / 模块 | 用到数据 | 支撑表 |
|---|---|---|
| 首页：冰箱总览、保鲜提醒、今日推荐、购物清单预览、家庭共享 | 库存 KPI、临期、推荐菜、清单、成员数 | FoodItem、Recipe、ShoppingListItem、Member |
| 扫描：摄像头识别 → 确认录入 → 同步家庭成员 | 识别结果（品名/建议保鲜天数/置信度/建议容器）、录入人 | FoodCatalog、FoodItem、ScanLog、Member |
| 库存：搜索、品类筛选、排序、食材卡片（录入人/时间/到期/存放状态/标签） | 库存明细 | FoodItem（含 recordedBy/recordMethod/keepDays/storage/label） |
| 菜谱：当前可用食材、今日推荐、更多推荐、口味偏好、收藏 | 菜谱库 + 库存匹配 + 偏好 | Recipe、RecipePreference、Member.preferences |
| 我的：成员管理、购物清单、收藏、通知设置、营养档案、关于 | 成员/清单/通知/营养 | Member、ShoppingListItem、Notification、ReminderSetting |
| 食材履历 / 追溯记录 | 来源、产地、批次、冷链、检测报告 | FoodTrace |
| 通知中心（未读 + 跳转） | 站内通知列表 | Notification |
| 营养档案（蛋白质/维C/膳食纤维/钙） | 库存与消耗的营养聚合 | FoodCatalog.nutrition + ConsumptionLog 计算 |
| 月度统计（本月省下金额、浪费、成员录入次数） | 消耗/过期记录、流水聚合 | ConsumptionLog、ScanLog |

### 3.2 表清单（v3）

| 表 | 用途 | 关键字段 |
|---|---|---|
| `FoodItem` | 当前库存（已有，需扩字段） | + `recordedBy`（录入成员）、`recordMethod`（camera/manual）、`keepDays`（建议保鲜天数）、`storage`（保鲜中/冷藏/冷冻/常温）、`label`（如“建议尽快喝”） |
| `ScanLog` | 扫描流水（已有，需扩字段） | + `recordedBy`、`recordMethod`、`keepDays` |
| `Member` | 家庭成员（管理员/成员、头像、负责品类） | name、role、avatar、responsibleCategory、preferences（JSON：口味标签） |
| `Device` | 设备元数据 | deviceId、name、memberId（绑定人）、lastSeenAt |
| `Container` | 容器管理（可自定义） | name、icon、sort、builtIn |
| `FoodCatalog` | 识别知识库（自动分类一致 + 营养 + 保鲜建议） | name、category、emoji、keepDays、defaultExpiryDays、suggestedContainer、aliases、nutrition（JSON）、source（ai/manual）、correctedAt |
| `FoodTrace` | 食材履历 / 追溯 | itemId、source（购买渠道）、origin（产地）、batch、coldChain、report（检测）、inTime |
| `ShoppingListItem` | 购物清单 | name、qty、unit、done、suggested（AI 建议）、source（manual/expiry/recipe）、boughtAt |
| `Notification` | 通知中心（站内） | type（expiry/recipe/member/shop/system）、title、desc、unread、view（跳转目标） |
| `ReminderRecord` | 定时推送幂等去重 | type、scheduledFor、payload、pushedAt（`@@unique([type, scheduledFor])`） |
| `ReminderSetting` | 通知/提醒设置 | key/value（JSON：开关、时间、临期阈值） |
| `ConsumptionLog` | 消耗 / 过期 / 浪费记录（统计与推荐输入） | name、reason（consumed/wasted/expired）、quantity、memberId、note |
| `Recipe` | 菜谱库（智能推荐） | name、emoji、grad、tag、timeMin、desc、nutr、ingredients（JSON：name/qty/status 有缺）、steps（JSON）、tags（JSON） |
| `WeeklyMealPlan` | 周度菜谱计划 | weekStart、date、recipeId、status（planned/done/skipped） |
| `RecipePreference` | 收藏 / 评分 / 做过次数 | recipeId、liked、rating、timesCooked、lastCookedAt |

### 3.3 示例（Prisma 模型，v3）

```prisma
model Member {
  id                   String   @id @default(cuid())
  name                 String   @unique
  role                 String   @default("member") // admin | member
  avatar               String?
  responsibleCategory  String?
  preferences          String?  // JSON：["清淡","家常"]
  createdAt            DateTime @default(now())
}

model Device {
  id         String    @id @default(cuid())
  deviceId   String    @unique
  name       String?
  memberId   String?
  lastSeenAt DateTime?
  createdAt  DateTime  @default(now())
}

model Container {
  id        String   @id @default(cuid())
  name      String   @unique
  icon      String?
  sort      Int      @default(0)
  builtIn   Boolean  @default(false)
  createdAt DateTime @default(now())
}

model FoodCatalog {
  id                 String   @id @default(cuid())
  name               String   @unique
  category           String?
  emoji              String?
  keepDays           Int?     // 建议保鲜天数（扫描页展示）
  defaultExpiryDays  Int?
  suggestedContainer String?
  aliases            String?  // JSON 数组
  nutrition          String?  // JSON：{ protein, vitaminC, fiber, calcium }
  source             String   @default("ai") // ai | manual
  correctedAt        DateTime?
  createdAt          DateTime @default(now())
  updatedAt          DateTime @updatedAt
}

model FoodItem {
  id           String    @id @default(cuid())
  deviceId     String
  memberId     String?   // 录入成员
  name         String
  category     String?
  emoji        String?
  container    String
  quantity     Int       @default(1)
  recordMethod String    @default("camera") // camera | manual
  keepDays     Int?      // 建议保鲜天数
  storage      String?   // 保鲜中 | 冷藏中 | 冷冻 | 常温
  label        String?   // 如“建议尽快喝”
  scannedAt    DateTime
  expiryDate   DateTime?
  daysLeft     Int
  confidence   Float
  note         String?
  imagePath    String?
  createdAt    DateTime  @default(now())
  updatedAt    DateTime  @updatedAt

  @@unique([name, container, deviceId])
  @@index([container])
}

model FoodTrace {
  id        String   @id @default(cuid())
  itemId    String   @unique
  source    String?  // 盒马鲜生…
  origin    String?  // 产地
  batch     String?
  coldChain String?  // 冷链说明
  report    String?  // 检测报告
  inTime    DateTime?
  createdAt DateTime @default(now())
}

model ShoppingListItem {
  id        String    @id @default(cuid())
  name      String
  qty       Int       @default(1)
  unit      String?
  done      Boolean   @default(false)
  suggested Boolean   @default(false)
  source    String    @default("manual") // manual | expiry | recipe
  boughtAt  DateTime?
  createdAt DateTime  @default(now())
}

model Notification {
  id        String   @id @default(cuid())
  type      String   // expiry | recipe | member | shop | system
  title     String
  desc      String?
  unread    Boolean  @default(true)
  view      String?  // 跳转目标：remind / recipe:0 / inv / shop / members …
  createdAt DateTime @default(now())
}

model ReminderRecord {
  id           String    @id @default(cuid())
  type         String
  scheduledFor DateTime
  payload      String?
  pushedAt     DateTime?
  createdAt    DateTime  @default(now())

  @@unique([type, scheduledFor])
}

model ReminderSetting {
  id    String @id @default(cuid())
  key   String @unique
  value String // JSON
}

model ConsumptionLog {
  id        String   @id @default(cuid())
  name      String
  reason    String   // consumed | wasted | expired
  quantity  Int      @default(1)
  memberId  String?
  note      String?
  createdAt DateTime @default(now())
}

model Recipe {
  id          String   @id @default(cuid())
  name        String   @unique
  emoji       String?
  grad        String?
  tag         String?
  timeMin     Int?
  desc        String?
  nutr        String?  // JSON
  ingredients String   // JSON：[{ name, qty, status: 有|缺 }]
  steps       String?  // JSON 数组
  tags        String?  // JSON 数组
  createdAt   DateTime @default(now())
  updatedAt   DateTime @updatedAt
}

model WeeklyMealPlan {
  id        String   @id @default(cuid())
  weekStart DateTime
  date      DateTime
  recipeId  String
  status    String   @default("planned")
  createdAt DateTime @default(now())

  @@unique([date, recipeId])
}

model RecipePreference {
  id           String    @id @default(cuid())
  recipeId     String    @unique
  liked        Boolean   @default(false)
  rating       Int?
  timesCooked  Int       @default(0)
  lastCookedAt DateTime?
  updatedAt    DateTime  @updatedAt
}
```

### 3.4 落地优先级

- **第一批（软件端页面直接需要）**：`Member`、`FoodCatalog`、`ShoppingListItem`、`Notification`、`ConsumptionLog`、`Device`、`Container`，并给 `FoodItem`/`ScanLog` 扩 `recordedBy`/`recordMethod`/`keepDays`/`storage`/`label` 字段；
- **第二批（菜谱与营养演示）**：`Recipe`（预置种子菜谱）、`WeeklyMealPlan`、`RecipePreference`、`FoodTrace`；
- **第三批（定时推送）**：`ReminderRecord`、`ReminderSetting`。

### 3.5 硬件交互侧（数据库 / 后端同样要考虑）

| 硬件行为 | 后端 / 数据库设计 |
|---|---|
| 设备在线状态（Wi-Fi 链路） | `Device` 表（deviceId、name、firmwareVersion、memberId、lastSeenAt）；新增 `POST /api/device/heartbeat` 更新最后在线（>5 分钟未上报视为离线） |
| 扫描上报（放入/取出） | `POST /api/scan`（已有）：multipart → 识别 → `FoodItem`/`ScanLog`；响应加 `keepDays`（固件解析器忽略未知字段，兼容） |
| 待机屏显示临期 / 过期提醒 | `GET /api/device/state?deviceId=`：返回该设备视角的临期/过期列表 + 最近识别结果（固件可离线缓存的兜底数据） |
| 设备本地库存计数与云端一致性 | **以后端为准**：`/api/scan` 响应可附 `stockTotal`（该设备当前总件数）；固件本地 KV 仅作离线兜底展示 |
| 温度传感器（DS18B20，可选） | 新增 `TemperatureLog`（deviceId、tempC、readAt），由心跳带上或独立上报；异常触达 `ReminderRecord(type=temperature)` |
| 设备诊断 / UART 日志 | 新增 `DeviceLog`（deviceId、event、msg、createdAt）；固件 `[XZD]` 事件（LINK_UP/SCAN_START/SCAN_OK/LOW_CONF/OFFLINE）可经心跳附带上报，便于路演展示“设备在线记录” |
| 设备与成员绑定 | `Device.memberId`：设备归属成员，扫描默认录入人 = 绑定成员 |
| 安全说明 | 固件 TLS no-verify、无鉴权 → `/api/scan`、`/api/device/*` 原型阶段公开；上线前需加设备级鉴权（如设备 Token） |

```prisma
model Device {
  id              String    @id @default(cuid())
  deviceId        String    @unique
  name            String?
  firmwareVersion String?
  memberId        String?
  lastSeenAt      DateTime?
  createdAt       DateTime  @default(now())
}

model DeviceLog {
  id        String   @id @default(cuid())
  deviceId  String
  event     String   // LINK_UP | SCAN_START | SCAN_OK | LOW_CONF | OFFLINE ...
  msg       String?
  createdAt DateTime @default(now())

  @@index([deviceId, createdAt])
}

model TemperatureLog {
  id        String   @id @default(cuid())
  deviceId  String
  tempC     Float
  readAt    DateTime
  createdAt DateTime @default(now())

  @@index([deviceId, readAt])
}
```

## 4. 环境变量（部署时写入服务器 .env）

```text
ARK_BASE_URL=https://ark.cn-beijing.volces.com/api/v3
ARK_VISION_MODEL=doubao-seed-2-1-turbo-260628
ARK_VISION_API_KEY=<支持视觉的方舟 Key>   # 优先；回退 ARK_API_KEY
```

> 注意：项目原 `ARK_API_KEY`（deepseek 文本模型）不支持图片；视觉识别必须用 `ARK_VISION_API_KEY`（read-image 那把 46 位 key）。密钥不写入本文档。

## 5. 部署（复用 workshop 服务器 / 域名 tuvmkt.com）

代码已在本机 midyear-workshop 工程验证通过（`next build` OK、接口冒烟测试 OK）。

```bash
# 在服务器上（与 workshop 相同部署方式）
git pull   # 或上传工程代码
cp .env.example .env   # 并填入 AUTH_SECRET / ARK_API_KEY / ARK_VISION_API_KEY / ARK_VISION_MODEL
docker compose up -d --build
docker compose exec app sh -c "mkdir -p data && touch data/app.db && npx prisma db push"
```

验证：

```bash
curl https://tuvmkt.com/api/health
curl https://tuvmkt.com/api/items
curl https://tuvmkt.com/api/reminders
```

固件烧录后自动上报到 `https://tuvmkt.com/api/scan`（固件配置 `XZD_SERVER_HOST=tuvmkt.com`）。

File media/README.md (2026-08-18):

# 食刻 ShiKe · 宣传素材存档

> 食刻 ShiKe：冰箱食品保质期智能管理产品（HsHH 2026 · 女性 AI 硬件黑客松参赛项目）
>
> 本目录集中归档项目宣传视频、产品宣传图与软件产品示意图，供路演、参赛、投稿与对外展示使用。

## 目录结构

```text
media/
├── 宣传视频/                  # 产品宣传 / 演示视频
├── 产品宣传图/                # 海报、产品实景图、3D 打印外壳预览
│   └── 3D打印外壳预览/        # 3D 打印外壳渲染预览图
└── 软件示意图/                # 手机 APP 与硬件设备界面示意图
    ├── 手机APP/               # 食刻 H5 / APP 界面截图
    └── 硬件设备界面/          # T5-E1 扫描台屏幕界面截图
```

## 宣传视频

| 文件 | 说明 |
|---|---|
| [食刻-宣传视频-原始素材.mp4](宣传视频/食刻-宣传视频-原始素材.mp4) | 产品演示原始视频素材（约 6 MB，MP4），源文件为 `pics/424_raw.MP4` |

## 产品宣传图

| 文件 | 说明 |
|---|---|
| [01-产品实景图-冰箱门展示.png](产品宣传图/01-产品实景图-冰箱门展示.png) | 产品吸附冰箱门实景展示图（含屏幕功能界面） |
| [02-易拉宝海报-A.png](产品宣传图/02-易拉宝海报-A.png) | 易拉宝宣传海报：产品定位 / 四大功能 / 适用场景 / 核心优势 |
| [03-宣传海报-B.jpg](产品宣传图/03-宣传海报-B.jpg) | 产品宣传海报（功能拆解版） |
| [04-易拉宝海报-C.png](产品宣传图/04-易拉宝海报-C.png) | 易拉宝宣传海报（另一版本） |
| [05-宣传长图-D.jpg](产品宣传图/05-宣传长图-D.jpg) | 产品宣传长图 |
| [06-宣传长图-高清.png](产品宣传图/06-宣传长图-高清.png) | 产品宣传高清长图（2590×6477） |
| [08-在线演示二维码.png](产品宣传图/08-在线演示二维码.png) | H5 在线演示入口二维码 |

### 3D 打印外壳预览

| 文件 | 说明 |
|---|---|
| [01-正面.png](产品宣传图/3D打印外壳预览/01-正面.png) | 外壳正面渲染预览 |
| [02-背面.png](产品宣传图/3D打印外壳预览/02-背面.png) | 外壳背面渲染预览 |
| [03-装配图.png](产品宣传图/3D打印外壳预览/03-装配图.png) | 外壳装配图预览 |
| [04-T5开发板-正面.png](产品宣传图/3D打印外壳预览/04-T5开发板-正面.png) | T5 开发板装配正面预览 |
| [05-T5开发板-背面.png](产品宣传图/3D打印外壳预览/05-T5开发板-背面.png) | T5 开发板装配背面预览 |
| [06-T5开发板-装配图.png](产品宣传图/3D打印外壳预览/06-T5开发板-装配图.png) | T5 开发板整体装配图预览 |
| [07-T5开发板-确认图.png](产品宣传图/3D打印外壳预览/07-T5开发板-确认图.png) | T5 开发板结构确认图预览 |

> 3D 打印外壳的 STL 源文件与建模脚本位于仓库 `hardware/case-3d/`。

## 软件产品示意图

### 手机 APP

| 文件 | 说明 |
|---|---|
| [01-首页.png](软件示意图/手机APP/01-首页.png) | APP 首页：库存总览 / 保鲜提醒 / 今日菜谱 / 购物清单 / 家庭共享 |
| [02-我的库存.png](软件示意图/手机APP/02-我的库存.png) | 我的库存页：库存统计 / 分类筛选 / 临期提醒 |
| [03-我的库存-版本B.jpg](软件示意图/手机APP/03-我的库存-版本B.jpg) | 我的库存页（另一版本） |
| [04-营养分析.jpg](软件示意图/手机APP/04-营养分析.jpg) | 营养分析页：饮食均衡评分 / 摄入占比 / 7 天趋势 |
| [05-菜谱推荐.png](软件示意图/手机APP/05-菜谱推荐.png) | 菜谱推荐页：根据库存食材推荐菜谱 |
| [06-扫描识别.jpg](软件示意图/手机APP/06-扫描识别.jpg) | 扫描识别页：识别成功示例（西兰花 · 建议保鲜 3 天） |
| [07-扫描识别-版本B.jpg](软件示意图/手机APP/07-扫描识别-版本B.jpg) | 扫描识别页（另一版本） |

### 硬件设备界面

| 文件 | 说明 |
|---|---|
| [01-待机页.png](软件示意图/硬件设备界面/01-待机页.png) | 设备待机页（时钟 / 临期提醒 / 今日菜谱） |
| [02-拍照倒计时.png](软件示意图/硬件设备界面/02-拍照倒计时.png) | 扫描模式拍照倒计时 |
| [03-识别中.png](软件示意图/硬件设备界面/03-识别中.png) | AI 识别中 |
| [04-识别结果-放入.png](软件示意图/硬件设备界面/04-识别结果-放入.png) | 识别结果 · 放入食材 |
| [05-识别结果-取出.png](软件示意图/硬件设备界面/05-识别结果-取出.png) | 识别结果 · 取出食材 |
| [06-识别失败-重拍.png](软件示意图/硬件设备界面/06-识别失败-重拍.png) | 识别失败 · 提示重拍 |
| [07-网络错误.png](软件示意图/硬件设备界面/07-网络错误.png) | 网络错误提示 |
| [08-断网离线.png](软件示意图/硬件设备界面/08-断网离线.png) | 断网离线提示 |
| [09-启动页.png](软件示意图/硬件设备界面/09-启动页.png) | 设备启动页 |
| [10-硬件界面-总览.png](软件示意图/硬件设备界面/10-硬件界面-总览.png) | 硬件界面全流程总览 |

> 上述硬件界面截图的交互式 HTML 源文件位于本仓库 `硬件界面-烧录AI参考/`（未随本目录发布）。

## 备注

- 所有素材均为原文件复制归档，未做压缩或修改；原始文件保留在工作目录对应位置。
- 手机 APP 界面截图与硬件设备界面截图来自演示数据与真实扫描流程。

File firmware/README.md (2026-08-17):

# 食刻 固件（T5-E1 · TuyaOpen）

> 硬件烧录源码：放在冰箱 / 零食柜旁的扫描台固件，T5-E1（SPARKLEIOT T5AI DEV）单板。

## 功能

待机（临期提醒 + 放入 / 取出）→ 3 秒半透明倒计时 → 板载 GC2145 拍照 → “咔嚓” → HTTPS 上传 `https://tuvmkt.com/api/scan` → 结果页（品名 / 时间 / 保质期 / 建议容器）→ 确认或重拍；断网显示本地最近记录。

## 目录

```text
firmware/
├── CMakeLists.txt        # 构建脚本
├── app_default.config    # 板卡选择（SPARKLEIOT_T5AI_DEV）
├── include/              # app_xzd_*.h（含配置 app_xzd_cfg.h）
└── src/                  # app_xzd.c 状态机 / net 上传 / ui / audio / font
```

## 构建与烧录

```bash
# 构建（TuyaOpen SDK 环境）
cd source/embedded && tos.py build
# 产物：source/embedded/dist/copy_1.0.0/copy_QIO_1.0.0.bin

# 烧录（端口以 tyutool list-ports 为准）
tyutool_cli --plain write -d t5 \
  -f source/embedded/dist/copy_1.0.0/copy_QIO_1.0.0.bin \
  -p /dev/cu.usbmodemXXXX -b 460800
```

## 配置（include/app_xzd_cfg.h）

- `XZD_SERVER_HOST / PATH`：tuvmkt.com /api/scan（线上后端）；
- `XZD_DEVICE_ID`：设备标识（xzd-t5e1-001）；
- `XZD_DEFAULT_CONTAINER`：默认容器（冰箱）；
- `XZD_WIFI_SSID / PASS`：⚠️ 已打码为占位符，**烧录前请填现场网络**，不要提交真实凭据。

> 本工程是 TuyaOpen 应用工程，TuyaOpenSDK 需单独拉取（/Users/lwl/TuyaOpenIDE/TuyaOpenSDK）。

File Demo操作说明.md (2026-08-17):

# 食刻 · Demo 操作说明

> 目标：现场工作人员和来访嘉宾**打开链接即可理解并演示**核心功能。

## 1. 演示链接

| 入口 | 链接 | 设备 |
|---|---|---|
| H5 手机端 | https://tuvmkt.com/shike-h5.html | 手机（iPhone 16 适配） |
| 大屏版 | https://tuvmkt.com/shike-web.html | 电脑 / 投屏 |
| 代码仓库 | https://github.com/wenlinl/shike | — |

## 2. 环境依赖（重要）

- 手机 / 电脑浏览器（Chrome / Safari 均可）；
- **扫描功能需要摄像头权限 + 联网**（识别走云端 https://tuvmkt.com/api/scan，火山方舟视觉模型）；
- 首页 / 库存 / 菜谱 / 我的等页面目前为演示数据（后端接口已就绪，扫描页为真实识别）；
- 可选硬件演示：T5-E1 扫描台（放入 / 取出 → 3 秒倒计时 → 咔嚓 → 屏幕显示结果），数据与 H5 同一后端。

## 3. 操作步骤（3 分钟内）

1. 手机打开 **H5 链接**，电脑打开**大屏链接**；
2. **首页**：看冰箱总览（在库种数 / 临期种数）、保鲜提醒、今日推荐、购物清单预览、家庭共享；
3. 点底部「**扫描**」→ 允许摄像头 → 把食材对准取景框 → 自动识别 → 显示**品名 / 建议保鲜天数 / 置信度 / 建议容器** → 点「确认录入」；
4. 切到「**库存**」：看到刚录入的食材（按容器、剩余天数排序）；「**菜谱**」：看能做的菜与还缺的食材；「**我的**」：成员、购物清单、通知中心；
5. 大屏版：演示库存排行、临期提醒、周度菜谱、月度统计面板；
6. 收尾：**“食刻在场，不浪费每一份食材。”**

## 4. 演示保底

- 断网 / 摄像头不可用时，页面自动回退演示数据，不影响讲解；
- 识别失败会提示“再扫一次”，属正常兜底流程。

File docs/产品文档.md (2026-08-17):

# 「食刻」产品文档（已实现版 · v3）

> Slogan：**食刻在场，不浪费每一份食材**
> 项目：食刻（Shike）· AI 冰箱食品管理
> 状态（2026-08-16）：**主链路已全部实现并上线**——硬件已烧录、后端已部署 tuvmkt.com、软件端 H5 可用。

---

## 1. 产品逻辑（当前真实可演示）

食刻是一台贴在冰箱上的智能扫描台：**把食品拿到镜头前扫一下，云端 AI 认出它是什么、能放多久，库存自动记账；屏幕和手机端随时告诉你谁快过期、能做什么菜。**

核心链路：**扫（按按钮拍照）→ 认（云端视觉 AI）→ 记（库存 ±1）→ 显（T5 屏幕 + H5 / 大屏）**

当前真实跑通的三个流程：

1. **放入**：点击【放入】→ 3 秒半透明大数字倒计时 → “咔嚓” → 板载摄像头拍照 → 上传识别 → 屏幕显示品名 / 时间 / 保质期 → 确认后库存 +1；
2. **取出**：点击【取出】→ 同样拍照确认 → 库存 -1；
3. **查看**：H5 / 大屏查看库存（按容器、剩余天数）、临期 / 过期提醒、能做的菜与还缺的食材、购物清单、通知。

识别失败或断网：屏幕提示“没看清，再扫一次”或“网络不好，先不扫描”，本地保留最近一次结果。

### 1.1 软件 App 端产品逻辑（H5 已实现页面）

移动端（食刻-H5手机端.html）底部 5 个 Tab，对应完整 App 产品逻辑：

1. **首页**：冰箱总览（在库种数 / 临期种数）、保鲜提醒（最近到期食材置顶）、今日推荐（按库存匹配菜谱）、购物清单预览、家庭共享（已同步成员数）、快捷入口（扫描食材 / 智能推荐 / 营养分析 / 食材履历 / 快速录入 / 菜谱灵感 / 健康推荐 / 追溯记录）；
2. **扫描**：摄像头取景 → 上传识别 → 结果（品名 / 建议保鲜天数 / 置信度 / 建议容器）→ 确认录入并同步家庭成员；面向老人儿童，对准即扫；
3. **库存**：搜索（名称 / 分类）、品类筛选、按剩余天数排序、KPI（种数 / 临期 / 成员数）、食材卡片（录入人 / 时间 / 到期 / 存放状态 / 标签）、临期横幅；
4. **菜谱**：当前可用食材、今日推荐卡片、更多推荐（换一批）、口味偏好（清淡 / 家常 / 微辣）、我的收藏；
5. **我的**：当前用户（家庭管理员）、绑定成员与容器、在库 / 临期 / 本月省下金额、功能菜单（家庭共享管理 / 购物清单 / 收藏 / 通知设置 / 营养档案 / 帮助反馈 / 关于食刻）。

子页面（弹层）：提醒列表、菜谱详情（有 / 缺食材、步骤、营养、耗时）、购物清单（勾选完成）、成员管理（角色 / 本月录入次数 / 负责品类）、通知中心（未读 + 跳转）、营养档案（蛋白质 / 维C / 膳食纤维 / 钙）、食材履历 / 追溯（来源 / 产地 / 批次 / 冷链 / 检测报告）、快速录入（手动）、口味偏好编辑、通知设置。

---

## 2. 已实现系统（架构）

```mermaid
flowchart LR
    subgraph DEV["硬件 · T5-E1 单板"]
        T5E1["T5-E1（SPARKLEIOT T5AI DEV）"]
        CAM["板载 GC2145 摄像头"]
        LCD["ST7789 240×320 触控屏"]
        AUD["板载音频（咔嚓声）"]
        T5E1 --- CAM & LCD & AUD
    end
    subgraph CLOUD["后端 · tuvmkt.com"]
        API["Next.js API：/api/scan 等 11 个接口"]
        AI["火山方舟视觉模型识别"]
        DB[("SQLite · 15 张表")]
        API --> AI
        API --> DB
    end
    subgraph SW["软件端"]
        H5["食刻-H5手机端.html（首页/扫描/库存/菜谱/我的）"]
        WEB["食刻-WebDemo.html（大屏）"]
    end
    T5E1 <-- "HTTPS multipart 上传" --> API
    API <-- "JSON" --> H5
    API <-- "JSON" --> WEB
```

| 端 | 组件 | 状态 |
|---|---|---|
| 硬件 | T5-E1 单板 + 固件（copy 工程 `app_xzd.c`） | ✅ 已烧录可扫 |
| 后端 | tuvmkt.com（Next.js + Prisma + SQLite，Docker 部署） | ✅ 已上线 |
| 视觉识别 | 火山方舟 `doubao-seed-2-1-turbo-260628`（关闭思考，3–5s） | ✅ 已接入 |
| 软件端 | 食刻-H5手机端.html / 食刻-WebDemo.html | ✅ 可用 |

---

## 3. 硬件（已实现）

### 3.1 单板规格（全部板载，无外挂）

| 部件 | 规格 |
|---|---|
| 主控 + 屏 | T5-E1（SPARKLEIOT T5AI DEV）：ST7789 240×320 触控彩屏（CST816X） |
| 摄像头 | 板载 GC2145 DVP（640×480 @15fps 预览） |
| 音频 | 内置 codec + 功放（spk_en GPIO7），“咔嚓”声 |
| 按键 | GPIO8（低有效，取消扫描用） |
| 存储 | microSD（SDIO：CLK=14、CMD=15、D0–D3=16~19） |
| 供电 | USB 5V（固定场景，不用锂电池） |

### 3.2 固件已实现流程（copy 工程）

```text
待机（显示最近临期提醒 + 放入 / 取出按钮）
 → 点击选择 → 实时预览 + 3 秒半透明大数字倒计时
 → 归零自动抓帧（JPEG）→ “咔嚓” → HTTPS 上传 https://tuvmkt.com/api/scan
 → 结果页：品名 / 时间 / 保质期 / 建议容器 → 确认（库存 ±1）或重拍
失败 → 提示重扫；断网 → 显示本地最近记录
```

- 配置：`app_xzd_cfg.h`（服务器 tuvmkt.com、路径 /api/scan、设备 ID `xzd-t5e1-001`、默认容器「冰箱」、上传超时 15s）；
- 烧录：`tos.py build` → `tyutool_cli write -d t5 -f copy_QIO_1.0.0.bin -p <port> -b 460800`（详见硬件烧录需求文档）。

---

## 4. 后端（已上线 tuvmkt.com）

### 4.1 接口（11 个，全部公开，原型阶段）

| 接口 | 用途 |
|---|---|
| `POST /api/scan` | 硬件 / H5 上传照片 → 识别 → 库存 ±1 → 识别库沉淀 → 返回扁平 JSON（code/name/scannedAt/expiryDate/daysLeft/suggestedContainer/confidence/keepDays/stockTotal） |
| `GET /api/items` | 库存（按容器筛选、剩余天数排序、成员 / emoji / 状态） |
| `GET /api/reminders` | 临期（≤3 天）与过期列表（未知保质期不误报） |
| `PATCH /api/items/[id]` | 手动修改容器分类 |
| `GET /api/members` | 家庭成员（角色 / 头像 / 负责品类 / 本月录入次数） |
| `GET /api/shopping-list` + `PATCH [id]` | 购物清单（单位 / 完成勾选） |
| `GET /api/notifications` + `PATCH [id]` | 通知中心（未读 / 跳转） |
| `GET /api/recipes` | 菜谱（自动算「有 / 缺」食材） |
| `POST /api/consume` | 消耗 / 过期 / 浪费记录（统计输入） |
| `GET /api/catalog` | 识别知识库（品类 / emoji / 保鲜天数 / 营养） |
| `POST /api/device/heartbeat`、`GET /api/device/state` | 设备在线与待机屏数据（后端已就绪，固件心跳待接） |

### 4.2 数据库（SQLite · 15 张表）

库存与流水：`FoodItem`、`ScanLog`；
软件端：`Member`、`Container`、`FoodCatalog`、`ShoppingListItem`、`Notification`、`ConsumptionLog`、`Recipe`、`WeeklyMealPlan`、`RecipePreference`、`FoodTrace`；
硬件端：`Device`、`DeviceLog`、`TemperatureLog`、`ReminderRecord`、`ReminderSetting`。

（字段与模型详见 [后端对接说明.md](./后端对接说明.md)）

### 4.3 视觉识别

- 模型：火山方舟 `doubao-seed-2-1-turbo-260628`（`thinking disabled` + 短提示，实时识别）；
- 低置信（<0.5）不入库，固件走“再扫一次”；
- 识别结果自动写入 `FoodCatalog`，同一商品下次识别保持一致。

---

## 5. 软件端（App / H5 产品逻辑 · 已实现页面与数据状态）

| Tab | 功能逻辑 | 数据状态 |
|---|---|---|
| 首页 | 冰箱总览 KPI、保鲜提醒、今日推荐、购物清单预览、家庭共享、快捷入口 | 演示数据（items/reminders 接口已就绪） |
| 扫描 | 取景 → `POST /api/scan` → 品名 / 保鲜天数 / 置信度 / 建议容器 → 确认录入 | ✅ 真实接口 |
| 库存 | 搜索、品类筛选、排序、食材卡片、临期横幅 | 演示数据（`GET /api/items` 已就绪） |
| 菜谱 | 当前可用食材、今日推荐、更多推荐、口味偏好、收藏 | 演示数据（`GET /api/recipes` 已就绪） |
| 我的 | 成员管理、购物清单、收藏、通知设置、营养档案、食材履历 | 演示数据（members/shopping/notifications 接口已就绪） |

**子页面**：提醒列表、菜谱详情（有 / 缺）、购物清单勾选、成员管理、通知中心、营养档案、食材履历 / 追溯、快速录入、口味偏好、通知设置——页面均已实现，数据为演示数据，对应后端表已建（见 §4.2），接口待逐个接通。

- **食刻-H5手机端.html**：移动端主界面（iPhone 16 适配，底部 5 Tab + 弹层子页面）；
- **食刻-WebDemo.html**：大屏版（已接 `GET /api/items`，服务器数据优先、断网回退演示数据）。

---

## 6. 未实现（已从主流程删除 · 待办）

| 类别 | 未做项 |
|---|---|
| 硬件 | DS18B20 温度上报（表已建，固件未接）、DHT11 湿度、RFP602 称重、WS2812B 灯带、门磁、语音播报（DFR0760）、离线识别（HuskyLens）、条码扫码（已决定不做） |
| 推送 | 场景化推送（下班前弹窗）、每日 08:00 汇总、温度异常提醒（`ReminderRecord/Setting` 表已建，定时任务未做） |
| 菜谱 | 周度菜谱计划（`WeeklyMealPlan` 表已建，接口 / 种子未做）；口味偏好与收藏：**H5 页面已实现（演示数据），`RecipePreference` 接口待接** |
| 软件 | 营养档案、食材履历 / 追溯：**H5 页面已实现（演示数据），接口待接**（`FoodTrace` 表已建）；原生 App / 涂鸦小程序、家人远程推送未做 |
| 固件 | 设备心跳（后端接口已就绪，固件未调用） |

---

## 7. Demo 叙事（按真实流程）

1. 设备静置，T5 屏幕显示最近一次临期提醒；
2. 点【放入】→ 3 秒倒计时 → 把牛奶拿到镜头前 → “咔嚓” → 屏幕显示「光明鲜牛奶 · 时间 · 保质期」→ 确认；
3. H5 / 大屏演示：库存出现牛奶、菜谱里「西兰花炒蛋」自动算好哪些有 / 哪些缺；
4. 彩蛋：过期贴纸再扫一次 → 低置信提示 / 过期状态展示；
5. 收尾：**“食刻在场，不浪费每一份食材。”**

> 演示保底：预录照片可离线跑“识别 → 提醒”链路。

---

## 8. 评审维度

- **人本价值**：减少食物浪费、守护家庭饮食安全；
- **技术实现**：T5-E1 单板拍照 + 云端视觉识别 + 端云库存闭环 + H5 联动，全链路真实运行；
- **创新价值**：把“拍照识物”落到家庭库存管理高频场景；
- **产品体验**：点一下 → 扫一下 → 咔嚓 → 看到结果，老人小孩都能用；
- **产品化潜力**：单板 + USB 供电，物料成本低，可量产；
- **表达与故事**：食刻在场，不浪费每一份食材。

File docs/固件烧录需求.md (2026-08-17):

# 「食刻」固件开发需求文档（给写烧录程序的 AI）

> 目标：在 T5-E1（SPARKLEIOT T5AI DEV）上实现「放入 / 取出」交互 + 3 秒倒计时拍照 + 照片上传云端解析，并把结果展示在屏幕。
> 起点工程：`/Users/lwl/TuyaOpenIDE/projects/copy`（已是「点按拍照」样板：GC2145 实时预览上屏 + 触控定格 + UART0 上报，直接在其上改造）。

## 1. 硬件与开发环境

| 项 | 值 |
|---|---|
| 主板 | T5-E1（SPARKLEIOT T5AI DEV），T5AI 平台，8MB Flash / 16MB PSRAM |
| 屏 | ST7789 240×320 触控彩屏（SPI0）；触控 CST816X（I2C1） |
| 摄像头 | 板载 GC2145 DVP（640×480 @15fps 预览） |
| 音频 | 板载 codec + 功放（spk_en GPIO7） |
| 按键 | GPIO8（低有效） |
| 字体 | 16×16 GB2312 点阵（HZK16）+ 8×16 ASCII；**禁止矢量 TTF / 抗锯齿**（详见 §7） |
| 工程 | `copy`（`source/embedded/src/app_photo.c`：预览 + 触控定格 5s） |
| 构建 / 烧录 | `tos.py build`；`tyutool_cli write -d t5 -f copy_QIO_1.0.0.bin -p <port> -b 460800` |

## 2. 交互流程（核心需求）

### 2.1 待机页

- 屏幕显示两个大按钮：**【放入】** 与 **【取出】**（可叠加显示临期 / 过期提醒文字）。

### 2.2 点【放入】→ 入库流程

1. 进入拍照预览：**背景 = 实时摄像头画面**（GC2145 预览上屏，参考 `app_photo.c`）；
2. 启动 **3 秒倒计时**：
   - 屏幕中央显示大号倒计时数字 **3 → 2 → 1**；
   - **数字为半透明**（透明度高，能看到背后实时画面）；
   - **数字占屏幕约一半**（240×320 屏，数字区域建议约 120×160 居中，字号最大可用）；
3. 倒计时归零 → **自动拍照**（抓当前帧）→ 板载音频“咔嚓”一声；
4. **照片实时上传云端**（见 §3 API 契约）；
5. 等待解析（超时建议 15s，显示“正在识别…”）；
6. 收到结果 → 屏幕显示：**品名、当天日期时间、保质期 / 到期日、建议容器**；
7. 用户确认 → 库存 +1 → 回待机页。

### 2.3 点【取出】→ 出库流程

- 与「放入」对称：拍照预览 → 3 秒半透明大数字倒计时 → 拍照上传 → 显示识别结果 → 确认后库存 -1；
- （若需求后续改为「列表选择取出」，以 PRD 最终版为准，固件留好入口。）

### 2.4 失败与兜底

- 上传失败 / 超时：屏幕提示“网络不好，请重试”，不丢本次动作，可重拍；
- 识别结果低置信：屏幕显示“没看清，请重新对准再拍”，不写入库存；
- 断网：显示本地最近一次库存与提醒 + “网络不好，先不扫描”。

## 3. 云端 API 契约（固件对接）

### 3.1 服务器与域名（复用 midyear-workshop 项目）

- 域名：**https://tuvmkt.com**（该项目的 `APP_URL`）；
- 服务器：该项目已部署的境外 VPS（Ubuntu 22.04 + Docker + Nginx + Certbot，`client_max_body_size 300m`）；
- 上传接口：`POST https://tuvmkt.com/api/scan`（**需后端在此项目中新增该路由**，契约见下，固件与后端可并行开发）。

### 3.2 请求

`multipart/form-data`：

| 字段 | 类型 | 说明 |
|---|---|---|
| `image` | JPEG 文件 | 640×480，质量 ~50–70 |
| `deviceId` | string | 设备标识（如 `xzd-t5e1-001`） |
| `action` | string | `in`（放入）/ `out`（取出） |
| `container` | string | `冰箱\|零食柜\|药盒\|调料柜\|主食柜` |
| `timestamp` | string | `2026-08-15 16:00:00` |

### 3.3 响应

```json
{
  "code": 0,
  "data": {
    "items": [
      {
        "name": "光明鲜牛奶",
        "scannedAt": "2026-08-15 16:00",
        "expiryDate": "2026-08-17",
        "daysLeft": 2,
        "suggestedContainer": "冰箱",
        "confidence": 0.92
      }
    ],
    "note": "可选：看不清的部分提示"
  }
}
```

失败：`{"code":1,"msg":"..."}`（固件按非 0 处理为失败，提示重试）。

### 3.4 云端处理（后端负责，固件不关心）

- 后端收到照片 → 调**火山方舟（Volcano Ark）视觉大模型**解析（品名 / 保质期 / 数量 / 建议容器）；
- API Key 用 **midyear-workshop 项目的 `ARK_API_KEY`**（位于 `/Users/lwl/Documents/Projects/midyear-workshop/.env` 与服务器 `.env`，密钥不写入固件，**设备端不持有任何 API Key**）；
- Ark 配置：`ARK_BASE_URL=https://ark.cn-beijing.volces.com/api/v3`；视觉模型建议 `doubao-seed-2-1-turbo-260628`（当前项目 `.env` 的 `ARK_CHAT_MODEL` 为文本模型，图片解析需用视觉模型，以后端实际可用为准）；
- 解析结果写入数据库（复用该项目服务器 + SQLite，新增 `food_items` 表；入库 / 出库 / 容器分类 / 提醒均以后端与软件端为准）。

### 3.5 设备心跳（可选，后端已就绪）

- 后端已提供 `POST https://tuvmkt.com/api/device/heartbeat`（JSON：`deviceId`、`firmwareVersion`、`tempC`、`event`、`msg`），用于记录设备最后在线、温度与诊断事件；
- 固件可择机调用（如 WiFi 连上后 / 每次扫描前后），不影响现有扫描主链路；不调也不阻塞 Demo。

## 4. 软件端（按 PRD / 设计文档）

- 网页端大屏（核心展示载体）：库存按容器统计、临期 / 过期提醒、周度菜谱（能做的菜 + 还缺的菜）、月度统计；
- 移动端：Wi-Fi 同步，月度统计、场景弹窗（下班前推送）、实时库存查询；
- 固件只负责：交互 + 拍照 + 上传 + 结果展示；其余全部由后端 / 网页 / App 承担。

## 5. 验收标准（固件）

- [ ] 待机页显示【放入】【取出】两个按钮；
- [ ] 点【放入】：实时画面作背景，半透明大数字 3→2→1（占屏约一半），归零自动拍照 + “咔嚓”；
- [ ] 照片成功上传 `https://tuvmkt.com/api/scan`，收到结果后屏幕显示品名 / 日期时间 / 保质期 / 建议容器；
- [ ] 上传失败有明确提示且可重试；断网有降级提示；
- [ ] 点【取出】走对称流程并确认出库。

## 6. 改造提示（基于 copy 工程）

- `app_photo.c` 当前逻辑：预览 → 触控定格 5s（仅显示不保存）。改造点：
  1. 触控定格 → 改为 **3s 半透明大数字倒计时**（屏 240×320，倒计时层用半透明 alpha 绘制，数字区域约占半屏）；
  2. 倒计时结束抓帧保存 JPEG（640×480）→ HTTP multipart 上传 `https://tuvmkt.com/api/scan`；
  3. 加【放入 / 取出】待机页与结果页（HTTP 返回 JSON 解析后上屏）；
  4. “咔嚓”走板载音频（或 GPIO 蜂鸣器备选）；
  5. 断网 / 失败分支（§2.4）。
- 网络栈：TuyaOpen 自带 lwip / HTTP client（参考 SDK examples 中 `http` / `netconn` 用法）。

## 7. 字体与字符集（屏显约束，必读）

> 屏幕是 240×320 低分辨率小屏，中文显示**必须用点阵字库，禁止矢量 TTF**。矢量字体在低分辨率下缩放会产生抗锯齿灰阶、丢像素、缺笔画，是糊字 / 毛边元凶。

| 用途 | 点阵规格 |
|---|---|
| 中文正文 / 按钮 / 结果页（品名、日期、保质期等） | **16×16 GB2312 点阵字库（HZK16 格式）**，原样点对点输出，不缩放 |
| 数字 / 字母 / 符号 | 8×16 或 16×16 ASCII 点阵 |
| 倒计时大数字 3→2→1 | 16×16 或 24×24 点阵，**整数倍（×2 / ×3）最近邻放大**，禁止非整数缩放 |

硬性约束：

1. **禁止 TrueType(.ttf) 等矢量字体**：AI 不要拿 ttf 做实时缩放渲染；
2. **禁止抗锯齿、灰度、亚像素渲染**：输出必须是纯 1-bit 二值点阵，每个字符像素严格对齐网格；
3. **字符集限定 GB2312 简体中文 + ASCII**（数字、字母、常用符号），不要全量 Unicode / 生僻字，减小字库体积、避免未知字符乱码碎像素；
4. 字号必须与点阵规格严格匹配：不要拿 12×12 强行放大显示，需要大字用整数倍放大；
5. 倒计时“半透明”仅指**位图字形 + 整数 alpha 混合**（数字背后能看到相机画面），字形本身仍是点阵，不做平滑处理。

### 7.1 可直接复制给烧录 AI 的字体提示模板

```text
目标硬件：T5-E1（SPARKLEIOT T5AI DEV），ST7789 240×320 低分辨率屏幕。
字体方案：中文用 16×16 GB2312 点阵字库（HZK16 格式），数字 / 字母用 8×16 或 16×16 ASCII 点阵；
倒计时大数字用 24×24 点阵按整数倍（×2 / ×3）最近邻放大。
硬性要求：禁止矢量 TTF、禁止抗锯齿、禁止灰度、禁止亚像素渲染；
输出纯 1-bit 二值点阵，每个字符像素严格对齐网格。
字符集：仅 GB2312 简体中文 + 数字字母 + 常用符号，剔除生僻字与全量 Unicode；
固件所有界面文案（待机、按钮、提示、结果页）必须全部在字库字符集内，避免缺字乱码。
```

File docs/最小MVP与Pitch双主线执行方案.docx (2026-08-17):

食 刻

最小 MVP 与 Pitch 双主线执行方案

从 8 月 14 日晚到 8 月 16 日 12:00｜新方案确认版

共同判断 我们交付的不是一台完善的量产冰箱硬件，而是一个足够真实的「扫一下即知」核心体验 Demo——点击选择补给或消耗，把食品拿到镜头前扫一下，就知道它是什么、能放多久、该怎么办；再配上一个让评委相信“这件事值得被做、与每个家庭有关”的完整故事。Pitch 与硬件 Demo 同等重要，两条主线从今晚开始并行。——食刻在场，不浪费每一份食材。

# 1. 成功标准：MVP 只证明 3 件事

# | 必须证明 | Demo 中如何被看见

1 | 它“看得懂”扫进来的食品 | 扫一下牛奶，识别出品名与保质期：例如「光明鲜牛奶 · 8 月 17 日到期」，而不是只给一句“看到一盒奶”。
2 | 待机时就知道谁快过期 | 屏幕默认显示临期 / 过期提醒并置顶；提前 3 天说“记得喝”，过期说“别喝了，该扔了”。
3 | 补给还是消耗，只需点一下 | 点击屏幕先选“补给 / 消耗”，再按扫描；库存自动 +1 / -1，看不清绝不瞎猜日期。

一句话验收 一张照片 + 补给/消耗 + 容器 → 每条物品的品名、保质期与一句可执行提醒；看不清时不猜，而是明确请求重新对准重拍。

# 2. 唯一技术主链路

T5-E1 触控（补给/消耗）→ 按【扫描】“咔嚓” → 板载 GC2145 拍照 → Wi-Fi → 服务器 / 视觉 LLM → 库存 + 到期 JSON → 屏幕 + 网页大屏 + 涂鸦 App
再按扫描 → 立即重新拍摄 → 新结果

输入：当前 JPEG 照片 + 补给/消耗动作 + 容器选择（冰箱 / 零食柜 / 药盒 / 调料柜 / 主食柜）+ 已入库清单与上一条提醒。

输出：仅保留 readable / expired / unclear 三种状态，以及每条物品的品名、保质期日期、剩余天数、建议容器和一条短、明确、可执行的中文提醒。

- readable：光明鲜牛奶，8 月 17 日到期，还有 3 天，记得喝。
- expired：牛奶已经过期 1 天，别喝了，该扔了。
- unclear：没看清，请把食品放到镜头正前方，再扫一次。

# 3. Demo 三场景：从功能闭环到情绪闭环

场景 | 动作 | 设备回应 | 证明什么
补给扫描 | 选“补给”→ 牛奶放到镜头前 → 按扫描 | “咔嚓”→ 屏幕显示“光明鲜牛奶 · 2026-08-15 16:00 · 保质期至 8月17日” | 看懂内容 + 自动入库
待机提醒 | 不操作时看屏幕 / 下班前收到推送 | 屏幕置顶“牛奶还有 3 天到期”；网页 / App 同步 | 主动管理，不是被动扫描
消耗 + 家人可见 | 选“消耗”→ 扫一下 / 打开网页大屏 | 库存 -1；网页大屏与 App 显示库存与剩余天数 | 闭环到人：自己和家人

# 4. 明确不做：所有非核心功能移入 Roadmap

冻结边界 以下内容可以在 Pitch 里讲未来愿景，但本次不进入工程任务，也不能阻塞主 Demo。

- 不做多容器实体传感器布点与门体适配；Demo 用一台扫描台 + T5 触控，拍固定角度。
- 不做连续视频监控与历史回放；只在按扫描按钮时拍照，一次 1 张。
- 不做电商下单、自动补货、多人权限体系；第一版交互只有“选 + 扫 + 看”。
- 不做称重全自动库存（RFP602 仅演示可选）、条码扫码、自训练识别模型、完整移动端 App。
- 不做 PCB、复杂电源、量产外壳；USB / 充电宝供电，用纸模、泡沫板或 3D 打印完成产品感。

# 5. 五人分工：每个人有唯一负责到底的交付

角色 | 核心交付 | 完成定义 / 禁区
A｜视觉链路 | T5-E1 板载 GC2145 拍照、“咔嚓”板载音频、联网上传服务器 | 服务器稳定收到 JPEG 即完成；不做 AI、App、电源优化。
B｜AI + 云端 | 图片 + 补给/消耗 + 容器 → 视觉模型 → 品名 / 保质期 JSON API | 覆盖 readable / expired / unclear；保留低置信兜底、去重；不等待真硬件，可先用手机图片。
C｜T5-E1 触控 + 网页大屏 + 涂鸦 | 待机提醒 / 补给消耗选择 / 结果显示 + 网页大屏 + 涂鸦 DP | 触控流程三项完成即停止加功能；不碰温度、称重。
D｜Pitch / Story | 3 分钟与 5 分钟讲稿、PPT 结构、每人台词 | 控制叙事节奏：先人和问题，再产品与 Demo，最后才讲技术。
E｜Demo Director / Product Owner | 场景、外形、集成、QA、取舍、备用方案 | 拥有砍功能权；负责演示食材、日期贴纸、摆放位置、彩排、备用图片和演示视频。

协作原则：A/B/C 负责让核心链路真实运行；D/E 用接近一半精力保证故事、产品表达与演示被记住。任何跨角色协助都不能模糊最终责任人。

# 6. Pitch 主线：让 Demo 成为故事的答案

第一幕｜从冰箱开始：不是不会做饭的人太多，而是“放进去就忘了”的人太多——冰箱是家里最容易被遗忘的库存系统。

第二幕｜放大共同处境：独居青年囤了又忘、异地子女看不见父母冰箱、长辈舍不得扔过期食品。“没发现过期”从不是某一种人的问题。

第三幕｜拿出食刻：我们没有再做一个备忘录 App，而是做一个替你“看见、记住、喊一声”的冰箱管家。

第四幕｜现场 Demo：点击选择补给 → 扫一下 → 咔嚓 → 屏幕显示品名和保质期 → 网页同步菜谱。停两秒。

第五幕｜技术与愿景：再解释 T5 触控、拍照识别、库存 JSON、容器分类与网页大屏；收束到“食刻在场，不浪费每一份食材”。

# 7. 里程碑与冻结规则

时间 | 阶段目标 | 每个角色的最低交付 / 闸门
8/14 晚 | 拆风险、各自跑通 | A 上传照片；B 手机图出 JSON；C T5 触控显示服务器文字 + 蜂鸣；D 完整故事骨架；E 三场景、外形草图、演示道具方案。任何高风险环节今晚必须暴露。
8/15 上午 | 第一次合流 | GC2145 板载拍照 → AI → T5 / 网页大屏首次端到端跑通，再接补给消耗与涂鸦 App。接口格式从此冻结，只允许修兼容问题。
8/15 下午 | 稳定主链，不加功能 | 优化识别准确率、延迟、去重、unclear 兜底、扫描按钮稳定性。18:00 闸门：主 Demo 连续成功 3 次。未通过则全员救主链。
8/15 晚 | 从 Build 转向 Show | 装外壳、布置扫描台与日期贴纸、完成 PPT、录备用视频、全流程彩排；确定主持人、设备操作者和故障切换口令。
8/16 上午 | 只修致命问题 | 10:00 代码冻结。之后只做设备、供电、网络、Token、线材、备用图片 / 视频检查与完整彩排。
8/16 12:00 | 停止开发，进入交付 | PPT、设备、演示道具、备份材料全部就位；不再接受“最后加一个功能”。

# 8. 冻结规则与降级方案

- 接口冻结：8/15 上午首次端到端跑通后，字段和调用方式不再重构。
- 功能冻结：8/15 12:00 后不新增功能；新增想法统一进 Roadmap。
- 演示闸门：8/15 18:00 前主路径须连续成功 3 次，否则暂停外观小优化，全员只修主链。
- 代码冻结：8/16 10:00 后只允许修复会导致 Demo 失败的致命问题，并要求立即复测。
- 降级优先级：实时硬件 Demo → 预置图片驱动真 AI / 真播报 → 本地录屏 / 备用视频。无论降级到哪层，故事和现场节奏不变。

# 9. 最终验收清单

类别 | 12:00 前必须确认
核心体验 | readable / expired / unclear / 重扫均有明确输出；补给与消耗闭环；连续三轮成功。
设备 | T5-E1（屏/触控/板载摄像头）、蜂鸣、门磁、供电、线材、热点均可用；网页大屏正常刷新；外壳不遮挡镜头和按钮。
AI / 云端 | Token 有效；接口可访问；无重复播报；低置信不乱报日期；周度菜谱与下班前推送可演示。
Pitch | 3 分钟与 5 分钟版本均可讲；每人台词、交接、Demo 插入点和最后一句已确定。
备份 | 备用热点、线材、图片、预置返回、录屏 / 视频均离线可取。
现场 | 扫描台与日期贴纸、镜头角度有标记；故障时由谁切换备份已演练。

最后原则 先让核心体验是真的，再让它被看见、被理解、被记住。任何不能直接服务这三件事的工作，都不是这 40 小时里的优先级。

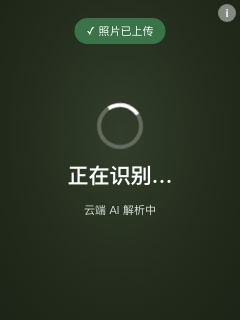
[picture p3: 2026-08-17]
media/软件示意图/硬件设备界面/03-识别中.png

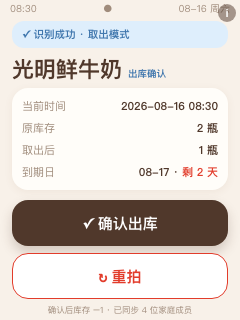
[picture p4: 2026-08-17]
media/软件示意图/硬件设备界面/05-识别结果-取出.png

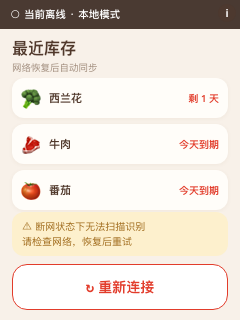
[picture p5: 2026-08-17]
media/软件示意图/硬件设备界面/08-断网离线.png

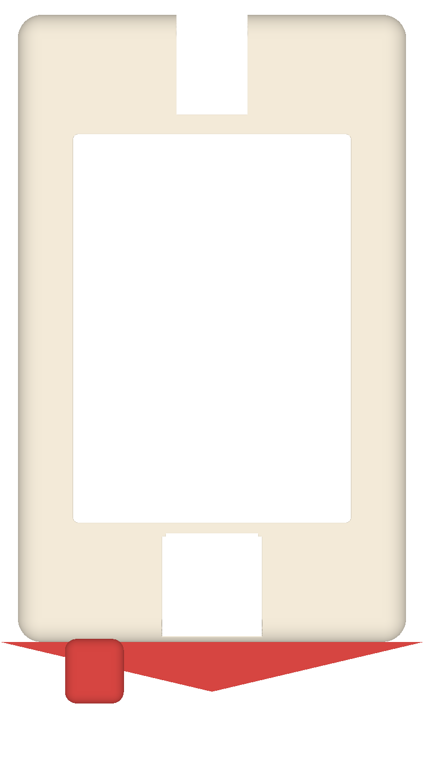
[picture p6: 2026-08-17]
media/产品宣传图/3D打印外壳预览/01-正面.png

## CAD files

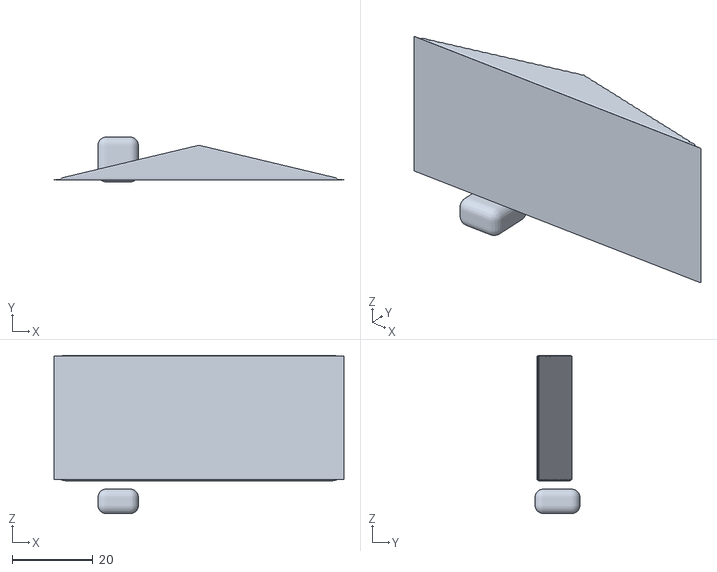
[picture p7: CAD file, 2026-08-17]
hardware/case-3d/食刻-屋顶-红色.stl
71.8 x 11.1 x 39.2

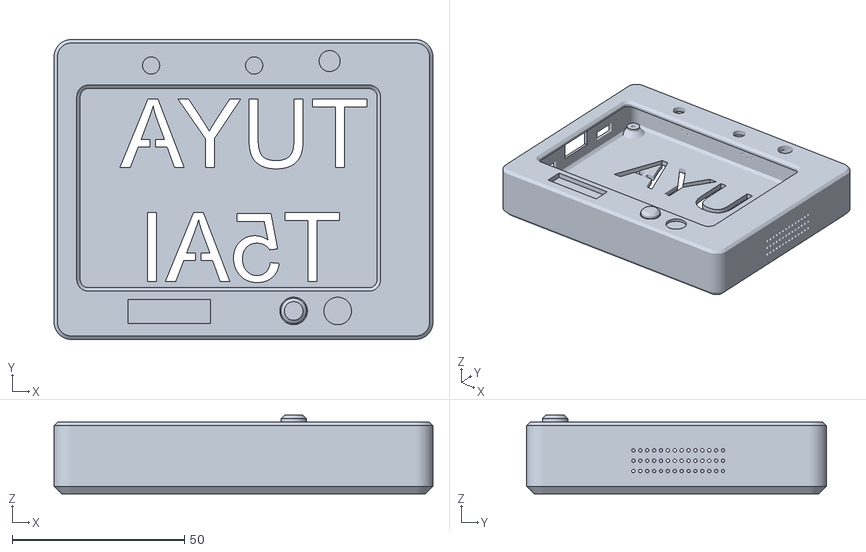
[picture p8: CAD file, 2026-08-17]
hardware/case-3d/T5+AI开发板.stl
110.0 x 87.0 x 22.8

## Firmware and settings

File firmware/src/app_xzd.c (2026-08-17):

/**
 * @file app_xzd.c
 * @brief 食刻 main state machine (reference UI implemented on hardware).
 *
 * Flow: BOOT -> IDLE -> [放入|取出] -> SCAN (live preview + 3s translucent
 * countdown) -> auto JPEG capture + shutter click -> RECOGNIZING (upload) ->
 * RESULT in/out / LOW_CONF / NET_FAIL / OFFLINE.
 *
 * All screens are drawn in the native portrait 240x320 space defined by the
 * reference UI (硬件界面-烧录AI参考). The camera preview is rotated 90 deg
 * counter-clockwise and downscaled to fill the portrait screen. The preview
 * is rendered directly from the camera's raw UYVY frames (deterministic byte
 * order), so no JPEG decode is involved in the live view.
 */
#include "tuya_cloud_types.h"
#include "tal_api.h"
#include "tal_uart.h"

#include "tdl_camera_manage.h"
#include "tdl_display_manage.h"
#include "tdl_tp_manage.h"
#include "tdl_button_manage.h"

#include "app_xzd.h"
#include "app_xzd_cfg.h"
#include "app_xzd_ui.h"
#include "app_xzd_net.h"
#include "app_xzd_audio.h"

/***********************************************************
************************macro define************************
***********************************************************/
#define XZD_CAM_WIDTH           640
#define XZD_CAM_HEIGHT          480
#define XZD_CAM_FPS             15
#define XZD_JPEG_BUF_CAP        (200 * 1024)
#define XZD_JPEG_MAX_SIZE_KB    60
#define XZD_JPEG_MIN_SIZE_KB    30
#define XZD_COUNTDOWN_MS        3000
#define XZD_CAPTURE_WAIT_MS     1200
#define XZD_DISP_W              240   /* native portrait viewport */
#define XZD_DISP_H              320
#define XZD_TP_POINT_MAX        5
#define XZD_STOCK_KV_KEY        "xzd_stock"

/* Result-page container chip geometry (portrait coordinates). */
#define XZD_CHIP_W              64
#define XZD_CHIP_H              24
#define XZD_CHIP_Y1             146
#define XZD_CHIP_Y2             174
#define XZD_CHIP_X0             22
#define XZD_CHIP_GAP            4

/* Diagnostic/report channel: UART0 (download port = USB serial on this board) */
#define XZD_REPORT_UART         TUYA_UART_NUM_0
#define XZD_REPORT_BAUD         115200

/***********************************************************
***********************typedef define***********************
***********************************************************/
typedef enum {
    XZD_STATE_BOOT = 0,
    XZD_STATE_STANDBY,
    XZD_STATE_PREVIEW,
    XZD_STATE_UPLOADING,
    XZD_STATE_RESULT,
    XZD_STATE_ERROR,
    XZD_STATE_OFFLINE,
} XZD_STATE_E;

typedef enum {
    XZD_ERR_NONE = 0,
    XZD_ERR_NET,
    XZD_ERR_CAPTURE,
    XZD_ERR_LOW_CONF,
} XZD_ERR_E;

typedef struct {
    char action[4];
    char container[XZD_SCAN_CONTAINER_LEN];
    uint8_t seq;
    uint8_t parity;
} XZD_UPLOAD_JOB_T;

const char *const XZD_CONTAINER_NAMES[XZD_CONTAINER_COUNT] = {
    "冰箱", "零食柜", "药盒", "调料柜", "主食柜"
};

/***********************************************************
***********************variable define**********************
***********************************************************/
static TDL_CAMERA_HANDLE_T   sg_cam_hdl = NULL;
static TDL_DISP_HANDLE_T     sg_disp_hdl = NULL;
static TDL_DISP_DEV_INFO_T   sg_disp_info;
static TDL_TP_HANDLE_T       sg_tp_hdl = NULL;
static TDL_BUTTON_HANDLE     sg_btn_hdl = NULL;

static TDL_DISP_FRAME_BUFF_T *sg_fb_out[2];        /* preview double buffer */
static volatile bool         sg_fb_out_busy[2];
static TDL_DISP_FRAME_BUFF_T *sg_ui_fb = NULL;     /* UI page buffer */
static TDL_DISP_FRAME_BUFF_T *sg_ui_base = NULL;   /* frozen photo copy */
static volatile bool         sg_ui_fb_busy = false;

static uint8_t              *sg_jpeg_buf = NULL;   /* captured JPEG (PSRAM) */
static uint8_t              *sg_upload_jpeg[2] = {NULL, NULL};
static volatile uint32_t     sg_upload_len[2] = {0, 0};
static volatile uint8_t      sg_upload_parity = 0;
static volatile bool         sg_upload_busy = false;
static volatile uint32_t     sg_jpeg_len = 0;
static volatile bool         sg_capture_req = false;
static volatile bool         sg_capture_done = false;
static volatile bool         sg_freeze_req = false;
static volatile bool         sg_frozen = false;
static uint32_t              sg_capture_wait_start = 0;

static volatile XZD_STATE_E  sg_state = XZD_STATE_STANDBY;
static char                  sg_action[4] = "in";
static char                  sg_container[XZD_SCAN_CONTAINER_LEN] = XZD_DEFAULT_CONTAINER;
static volatile uint8_t      sg_countdown_disp = 3;
static uint8_t               sg_countdown_last = 0;
static uint32_t              sg_countdown_start_ms = 0;
static uint32_t              sg_boot_start_ms = 0;

static QUEUE_HANDLE          sg_upload_q = NULL;
static volatile bool         sg_upload_finished = false;
static volatile XZD_NET_RESULT_E sg_last_net_result = XZD_NET_ERR_HTTP;
static volatile uint8_t      sg_upload_seq_sent = 0;
static volatile uint8_t      sg_upload_seq_done = 0;
static XZD_SCAN_RESULT_T     sg_result;
static uint32_t              sg_upload_start_ms = 0;
static uint8_t               sg_dots = 0;
static uint32_t              sg_last_dots_ms = 0;

static XZD_ERR_E             sg_err = XZD_ERR_NONE;
static int32_t               sg_stock_count = 0;
static XZD_SCAN_RESULT_T     sg_last_result;

static bool                  sg_tp_pressed = false;
static volatile bool         sg_btn_pressed = false;
static bool                  sg_calibrate = false;
static bool                  sg_report_uart_ready = false;
static THREAD_HANDLE         sg_upload_thrd = NULL;
static bool                  sg_last_online = false;
static THREAD_HANDLE         sg_housekeep_thrd = NULL;
static XZD_DEVICE_STATE_T    sg_devstate;
static volatile bool         sg_devstate_valid = false;
static char                  sg_last_event[24] = "";
static volatile bool         sg_ui_refresh = false;

/***********************************************************
***********************function define**********************
***********************************************************/
static void __xzd_report_uart_init(void)
{
    /* Disabled: UART0 is owned by the SDK debug log (460800) on this build.
     * The old 115200 report channel must not re-program the log UART. */
    sg_report_uart_ready = false;
}

static void __xzd_report(const char *line)
{
    char buf[160];
    int  len;

    if (false == sg_report_uart_ready) {
        __xzd_report_uart_init();
    }
    if (false == sg_report_uart_ready) {
        return;
    }
    len = snprintf(buf, sizeof(buf), "[XZD] %s\r\n", line);
    if (len > 0) {
        tal_uart_write(XZD_REPORT_UART, (const uint8_t *)buf, (uint32_t)len);
    }
}

static void __xzd_report_tap(uint16_t x, uint16_t y)
{
    char buf[48];
    int len = snprintf(buf, sizeof(buf), "TAP %u,%u", x, y);

    if (len > 0) {
        __xzd_report(buf);
    }
}

static void __xzd_render_standby(void);
static void __xzd_render_boot(void);
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

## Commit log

2026-08-16 食刻 ShiKe：冰箱食品保质期管理（HsHH 2026）— H5/大屏 Demo + 产品文档 + 后端参考代码
2026-08-16 docs: 更新仓库链接为 wenlinl/shike
2026-08-16 docs: 后端参考代码指向本仓库 backend/
2026-08-17 feat: 加入硬件烧录固件源码（T5-E1 TuyaOpen，WiFi 凭据打码）+ 构建烧录说明
2026-08-17 docs: 投资人视角全面更新 — 详细 README（理想使用场景 + 未来迭代方向），新增商业化/出海/磁吸门版方案/物料清单/3D 外壳材料
    [T5+AI开发板.stl, 食刻-屋顶-红色.stl]
2026-08-17 docs: 移除商业化分析报告 / 出海战略分析 / 物料清单（内部文档不上传）
2026-08-17 docs: 归档宣传素材（宣传视频 / 产品宣传图 / 软件示意图）
2026-08-17 docs: 对外文案统一为云端视觉AI实时识别（移除 3–5 秒表述）
2026-08-17 docs: 核心资料对齐本地通用版（贴冰箱定位/营养分析/目标人群/一键补货等）
2026-08-18 docs: 定位更新为对存量电器进行智能化+AI改造
2026-08-18 docs: 移除黑客松极简海报（宣传物料归档不再包含该图）
2026-08-18 docs: 宣传物料索引移除黑客松极简海报
2026-08-18 feat: H5 库存筛选框 + 妙用整合页 + 食物过期处理；后端补 shelf-life/手动录入/履历/收藏/消耗统计接口
2026-08-18 feat: 顶栏主题色/筛选图标区分/过期处理归档复原/购物清单增删/妙用精简/营养AI分析
2026-08-18 feat: 补充 nutrition 路由
2026-08-18 fix: 品牌栏透明红+页面同宽+固定占位；过期处理按钮等高等宽；复原按钮紧凑；购物清单添加入口美化
2026-08-18 fix: 品牌栏改为占位式 sticky（不悬浮覆盖），子页面弹层同样常驻品牌栏
2026-08-18 fix: 品牌栏固定常驻+内容独立滚动容器+子页面弹层从品牌栏下方开始（实测通过）
2026-08-18 fix: body 锁滚动+main 独立滚动+vh 兜底+品牌栏平边实占位，滚动不再悬浮
2026-08-18 fix: 禁用页面整体滚动，品牌栏固定不悬浮，内容仅在品牌栏下方独立滚动（实测：页面scrollTop=0、品牌栏区域无内容侵入）
2026-08-18 feat: 每页标题吸顶固定（紧贴品牌栏下方），滚动时标题常驻
2026-08-18 fix: 首页标题统一为 page-head 吸顶样式；妙用 Tab 图标改为与导航一致的 SVG 线条风格
